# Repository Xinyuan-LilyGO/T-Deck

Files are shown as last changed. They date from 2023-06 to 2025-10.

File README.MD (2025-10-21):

<h1 align = "center">✨ LilyGO T-Deck  ✨</h1>

## **English | [中文](README_CN.MD)**

## News:

1. T-Deck-Plus has assigned the pins on the **Grove** interface to the GPS module, so the **Grove** interface of T-Deck-Plus cannot be used.
2. T-Deck updated [TFT_eSPI ST7789 initialization sequence](https://github.com/Xinyuan-LilyGO/T-Deck/commit/6adb8884c689f174c29a6d7172a0daa367a582eb) on 20240726. Currently, the changes have not been pushed to the TFT_eSPI upstream branch. If you find that the screen display is incorrect during use, please check whether this is consistent with the initialization sequence in the warehouse.

## 1️⃣ Examples preview

````
examples 
├─Keyboard_ESP32C3       # ESP32C3 keyboard I2C slave
├─Keyboard_T_Deck_Master # T-Deck read from keyboard
├─LoRaWAN_Starter        # LoRaWAN example
├─Microphone             # Noise detection  
├─Touchpad               # Read touch coordinates 
├─GPSShield              # GPS Shield example
├─lvgl_example           # lvgl example
└─UnitTest               # Factory hardware unit testing           

````

## 2️⃣ Quick Start

### PlatformIO

1. Install [VisualStudioCode](https://code.visualstudio.com/) and [Python](https://www.python.org/)
2. Search for the `PlatformIO` plugin in the `VisualStudioCode` extension and install it.
3. After the installation is complete, you need to restart `VisualStudioCode`
4. After restarting `VisualStudioCode`, select `File` in the upper left corner of `VisualStudioCode` -> `Open Folder` -> select the `T-Deck` directory
5. Click on the `platformio.ini` file, and in the `platformio` column, cancel the sample line that needs to be used, please make sure that only one line is valid
6. Click the (✔) symbol in the lower left corner to compile
7. Connect the board to the computer USB
8. Click (→) to upload firmware
9. Click (plug symbol) to monitor serial output

Optional:

You can upload the assets contents for the speaker demo, using the "Upload Filesystem Image" on PlatformIO menu.

### ArduinoIDE

1. Install [Arduino IDE](https://www.arduino.cc/en/software)
2. In Arduino Preferences, on the Settings tab, enter the `https://raw.githubusercontent.com/espressif/arduino-esp32/gh-pages/package_esp32_index.json` URL in the `Additional boards manager URLs` input box. **Please pay attention to the version. The test phase is using 2.0.14. It is not certain that versions above 2.0.14 can run. When the operation is abnormal, please downgrade to a version below 2.0.14.** , As of 2024/08/02, TFT_eSPI does not work on versions higher than 2.0.14, see [TFT_eSPI/issue3329](https://github.com/Bodmer/TFT_eSPI/issues/3329)
3. Copy all the folders in the `T-Deck/lib` directory to `<C:\Users\UserName\Documents\Arduino\libraries>`. If there is no `libraries` directory, please create a new one. Please note that you are not copying the `lib` directory, but copying the folders in the lib directory
4. Open ArduinoIDE  ,`Tools` , Look at the picture to choose
    | T-Deck(ESP32S3)      | T-Keyboard(ESP32C3)  |
    | -------------------- | -------------------- |
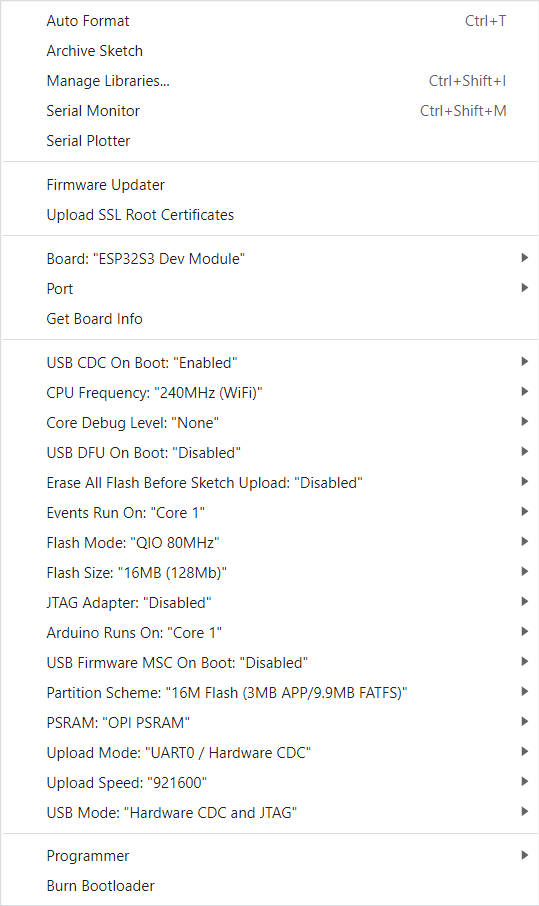
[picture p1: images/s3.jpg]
s3
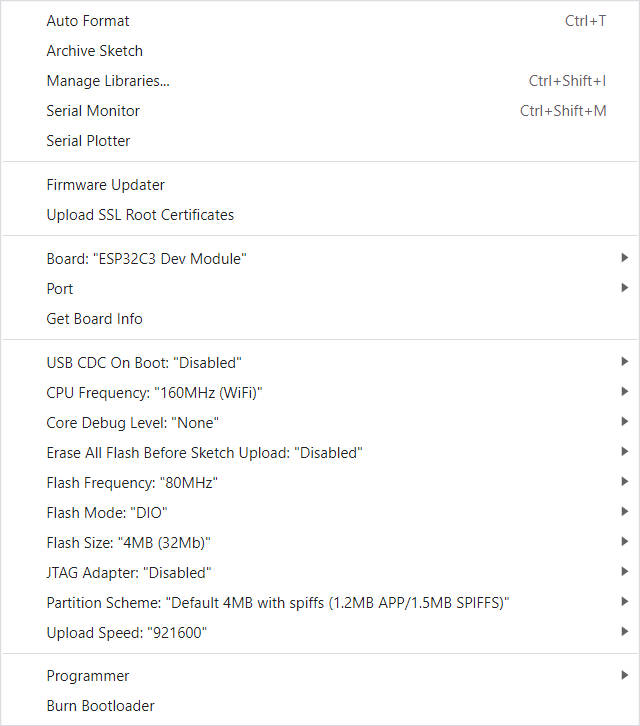
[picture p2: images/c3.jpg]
c3
    |  |  |
5. Insert USB into the PC and click Upload <If the upload fails, keep pressing the BOOT button, click RST, and then click Upload. When the upload is complete, click RST to exit the download mode>

## 3️⃣ Tips:

1. If a microphone is used, the GPIOO button cannot be used
2. If the sketch cannot be uploaded, then you need to press down the middle of the trackball, and then insert the USB, this means the chip is in the download mode, and then click to upload the sketch.
3. T-Keyboard the programming and burning interface of ESP32C3 is located at the 6Pin header on the side of the RST button, and the order starts from the top of the RST button, which are TX,RX,BOOT,RST,GND,VCC, You need to connect USB TO TTL externally to burn the keyboard firmware. For TTL without automatic download circuit, before powering on, short-circuit the BOOT Pin and GND, and then power on. At this time, T-Keyboard will enter the download mode. After the burning is completed, you need to disconnect GND and BOOT before running the program.

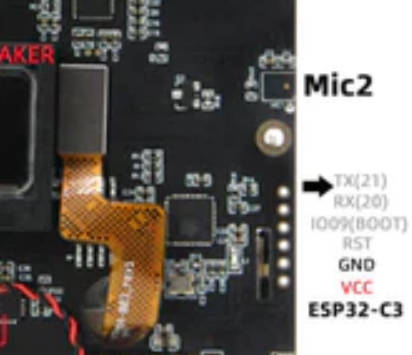
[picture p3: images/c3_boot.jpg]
c3_boot
   

4. T-Deck can't upload any sketch，Please enter the upload mode manually.
   1. Connect the USB-C cable
   2. Toggle the switch to ON
   3. Press and hold the center trackball
   4. Press the left reset button
   5. Upload sketch
   6. If you still cannot upload the sketch successfully according to the above method, please check whether the resistor in this [issue62](https://github.com/Xinyuan-LilyGO/T-Deck/issues/62) exists. Please remove it and test again.
   7. [How to enter download mode Youtube](https://youtu.be/29g97dYt9-g)

5. fatal error: esp_vad.h: No such file or directory
   1. See [issus](https://github.com/Xinyuan-LilyGO/T-Deck/issues/90#issuecomment-2980116659)

## 4️⃣ Where to buy:

1. [AliExpress](https://www.aliexpress.com/item/1005005692235592.html)
2. [LilyGo Store](https://www.lilygo.cc/products/t-deck)

## 5️⃣ Pins:

See [utilities.h](./examples//UnitTest//utilities.h)

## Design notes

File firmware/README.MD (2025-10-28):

# Write to new users

- This page provides a quick diagnosis of whether the hardware is normal. The firmware in the example table below provides quick testing of the hardware. Please follow the steps below to test
- [T-Deck Plus Touch Fix Record](https://youtu.be/CTdMXJvWZpA)
- [How to write firmware to T-Deck or T-Deck-Plus Record](https://www.youtube.com/watch?v=aSjUyzw_2F4)
- [Discussion about touch repair](https://www.reddit.com/r/meshtastic/comments/1jizmsb/tdeck_touchscreen_not_working_properly/)
- **Please note that if meshtastic is written, the port displayed after plugging in the computer USB is a virtual USB port, not a real port number. You must manually enter the download mode to perform the secondary flash. For how to enter the download mode, please see the FAQ below.**

# 1️⃣ Quickly diagnose hardware

| Firmware Name | description |
| --- | --- |
| [T-Keyboard_Keyboard_ESP32C3_250620.bin](./T-Keyboard_Keyboard_ESP32C3_250620.bin) | [T-Deck Keyboard C3 firmware][1] |
| [T-Deck_UnitTest_241220.bin](./T-Deck_UnitTest_241220.bin) | [T-Deck/T-Deck-Plus function test firmware][1] |
| [T-Deck-Plus-TouchFix_241025.bin](./T-Deck-Plus-TouchFix_241025.bin) | [T-Deck-Plus Touch Fix][2] |
| [T-Deck-Plus-TouchFix_241203.bin](./T-Deck-Plus-TouchFix_241203.bin) | [T-Deck-Plus Touch Fix][2] |
| [Meshtastic Online][https://flasher.meshtastic.org/] | [Meshtastic Online][https://flasher.meshtastic.org/] |

⚠⚠⚠

**T-Deck-Plus-TouchFix_241025.bin** Touch repair program, can only be flashed on rounded corner screens, please do not flash this on T-Deck rectangular screens, otherwise the screen touch will fail

**T-Deck-Plus-TouchFix_241025.bin** Touch repair program, can only be flashed on rounded corner screens, please do not flash this on T-Deck rectangular screens, otherwise the screen touch will fail

**T-Deck-Plus-TouchFix_241025.bin** Touch repair program, can only be flashed on rounded corner screens, please do not flash this on T-Deck rectangular screens, otherwise the screen touch will fail

[1]: https://www.lilygo.cc/products/t-deck
[2]: https://www.lilygo.cc/products/t-deck
[3]: https://www.lilygo.cc/products/t-deck

### Use ESP Download Tool

- Download [Flash_download_tool](https://www.espressif.com.cn/sites/default/files/tools/flash_download_tool_3.9.7_0.zip)

web_flasher

* Note that after writing is completed, you need to press RST to reset.
* When writing the keyboard firmware, you need to select ESP32-C3 in the chip type

### Use Web Flasher

- [ESP Web Flasher Online](https://espressif.github.io/esptool-js/)

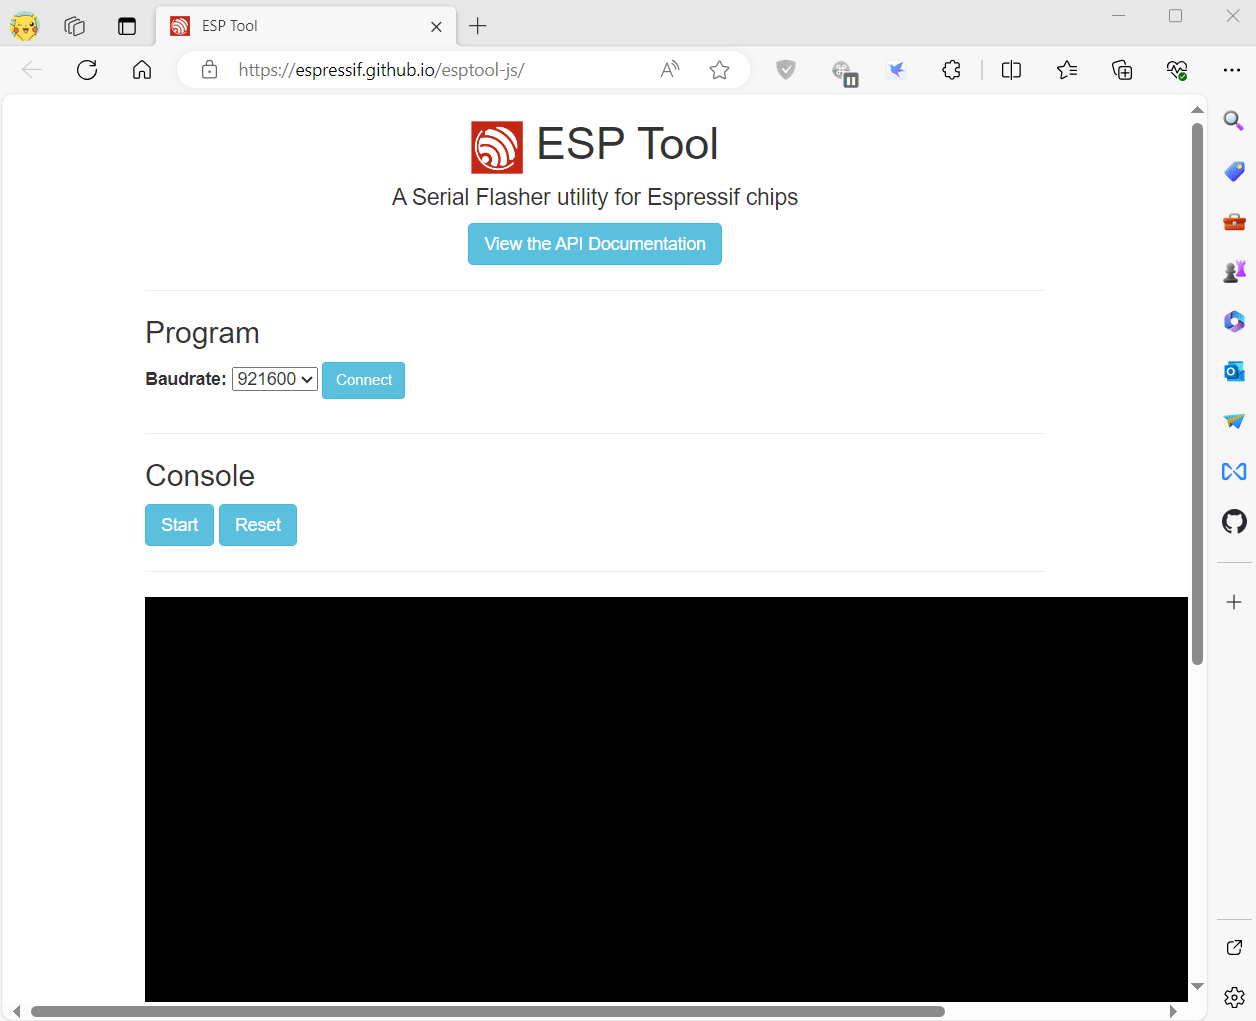
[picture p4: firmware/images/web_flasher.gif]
web_flasher


* Note that after writing is completed, you need to press RST to reset.

### Use command line

If system asks about install Developer Tools, do it.

```bash
python3 -m pip install --upgrade pip
python3 -m pip install esptool
```

In order to launch esptool.py, exec directly with this:

```bash
python3 -m esptool
```

For T-Deck/T-Deck-Plus use the following command to write

```bash
esptool --chip esp32s3  --baud 921600 --before default_reset --after hard_reset write_flash -z --flash_mode dio --flash_freq 80m 0x0 T-Deck_UnitTest_241004.bin

```

For ESP32-C3 Keyboard use the following command to write

```bash
esptool --chip esp32c3  --baud 921600 --before default_reset --after hard_reset write_flash -z --flash_mode dio --flash_freq 80m 0x0 firmware-c3-t-keyboard.bin

```

# 2️⃣FAQ

- Can't upload any sketch，Please enter the upload mode manually.
   1. Connect the board via the USB cable
   2. Press and hold the **BOOT** button , While still pressing the **BOOT** button (On the trackball above the keyboard, press down)
   3. Press **RST** button
   4. Release the **RST** button
   5. Release the **BOOT** button (If there is no **BOOT** button, disconnect IO0 from GND.)
   6. Upload sketch
   7. Press the **RST** button to exit download mode

- T-Keyboard the programming and burning interface of ESP32C3 is located at the 6Pin header on the side of the RST button, and the order starts from the top of the RST button, which are TX,RX,BOOT,RST,GND,VCC, You need to connect USB TO TTL externally to burn the keyboard firmware. For TTL without automatic download circuit, before powering on, short-circuit the BOOT Pin and GND, and then power on. At this time, T-Keyboard will enter the download mode. After the burning is completed, you need to disconnect GND and BOOT before running the program.

   c3_boot

## Touch Fix firmware

- Used to try to repair the touch when the touch does not work properly. If the hardware is not damaged, then open the serial after writing, you should be able to see the following log, slide your finger on the touch screen, and you can see the output sliding coordinates

   ```bash

   ESP-ROM:esp32s3-20210327
   Build:Mar 27 2021
   rst:0x15 (USB_UART_CHIP_RESET),boot:0x8 (SPI_FAST_FLASH_BOOT)
   Saved PC:0x420247ee
   SPIWP:0xee
   mode:DIO, clock div:1
   load:0x3fce3808,len:0x44c
   load:0x403c9700,len:0xbe4
   load:0x403cc700,len:0x2a38
   entry 0x403c98d4
   [    88][I][esp32-hal-psram.c:96] psramInit(): PSRAM enabled
   [    94][I][esp32-hal-i2c.c:75] i2cInit(): Initialising I2C Master: sda=18 scl=8 freq=100000
   [    94][I][SensorCommon.tpp:65] begin(): Using Arduino Wire interface.
   [    97][W][Wire.cpp:301] begin(): Bus already started in Master Mode.
   [   104][D][TouchDrvGT911.hpp:584] initImpl(): Probe address ....
   [   112][D][TouchDrvGT911.hpp:588] initImpl(): Probe address is : 0x5D
   [   138][I][TouchDrvGT911.hpp:644] initImpl(): Product id:911
   [   138][D][TouchDrvGT911.hpp:653] initImpl(): Current version char :41
   [   256][D][TouchDrvGT911.hpp:659] initImpl(): WriteConfig version char :0
   [   257][I][TouchDrvGT911.hpp:666] initImpl(): Firmware version: 0x1060
   [   260][I][TouchDrvGT911.hpp:668] initImpl(): Resolution : X = 240 Y = 320
   [   265][I][TouchDrvGT911.hpp:669] initImpl(): Vendor id:57
   [   270][I][TouchDrvGT911.hpp:670] initImpl(): Refresh Rate:10 ms
   [   276][I][TouchDrvGT911.hpp:671] initImpl(): MaxTouchPoint:5
   [   282][I][TouchDrvGT911.hpp:680] initImpl(): Interrupt Mode:  FALLING
   Init GT911 Sensor success!
   Pressed!
   2093ms X[0]:86  Y[0]:152 
   Pressed!
   2198ms X[0]:86  Y[0]:152 
   Pressed!

   ```

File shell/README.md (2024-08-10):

## DXF

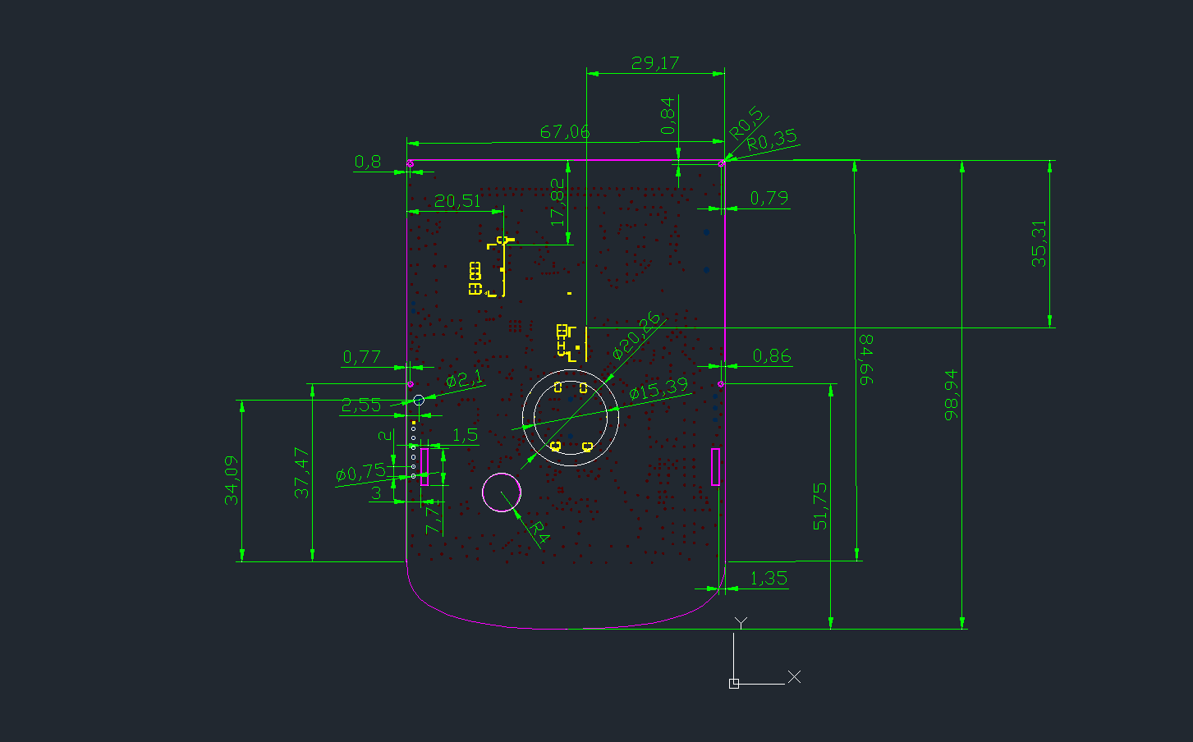
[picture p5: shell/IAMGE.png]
IAMGE


## PCB_3D

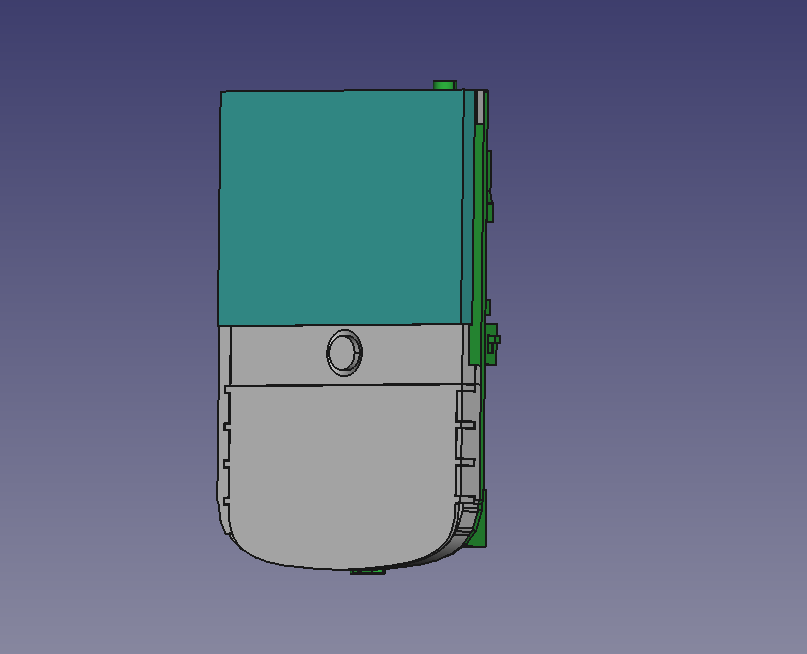
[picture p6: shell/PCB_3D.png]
PCB_3D


## SHELL_3D

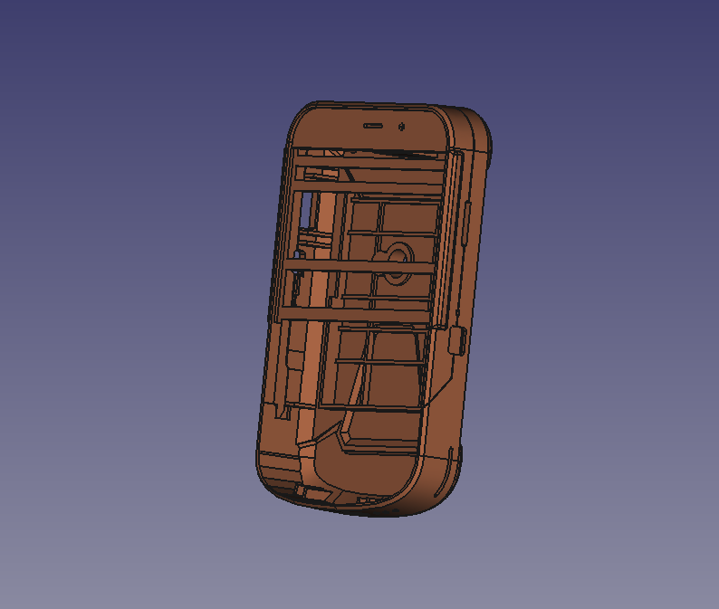
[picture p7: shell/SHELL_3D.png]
SHELL_3D


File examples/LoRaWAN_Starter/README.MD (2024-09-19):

## [LoRaWAN_Starter , Must read for new users](https://github.com/jgromes/RadioLib/blob/master/examples/LoRaWAN/LoRaWAN_Starter/notes.md)

## Operation screenshot

### [thethingsnetwork website](https://www.thethingsnetwork.org/)

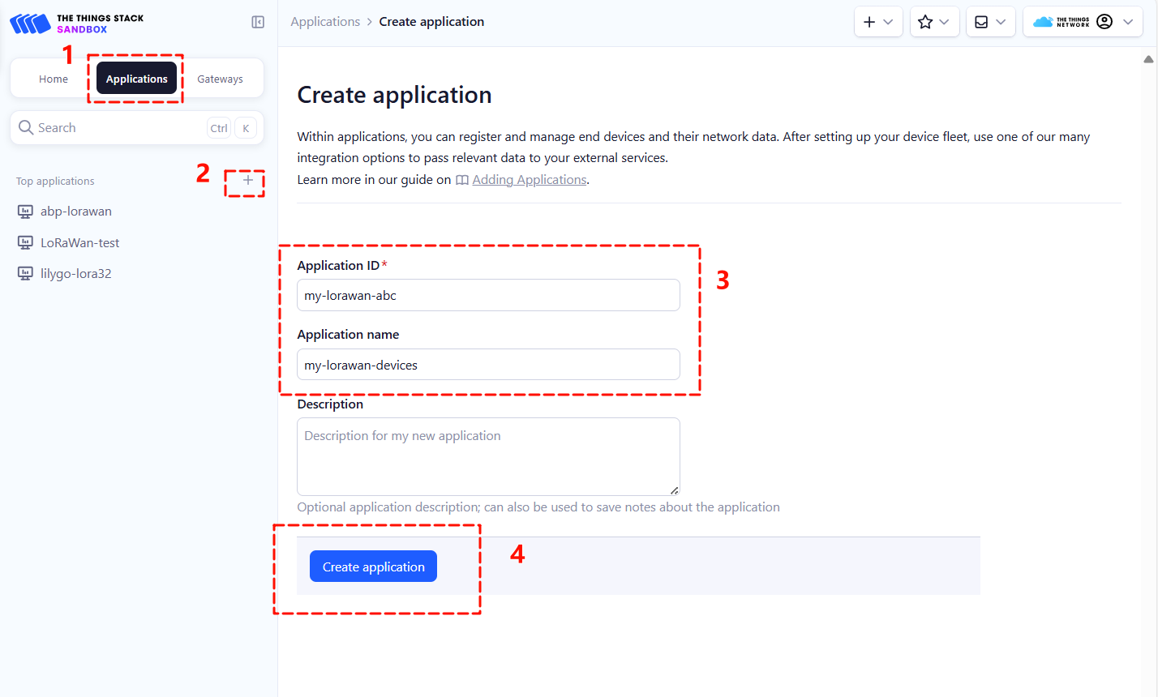
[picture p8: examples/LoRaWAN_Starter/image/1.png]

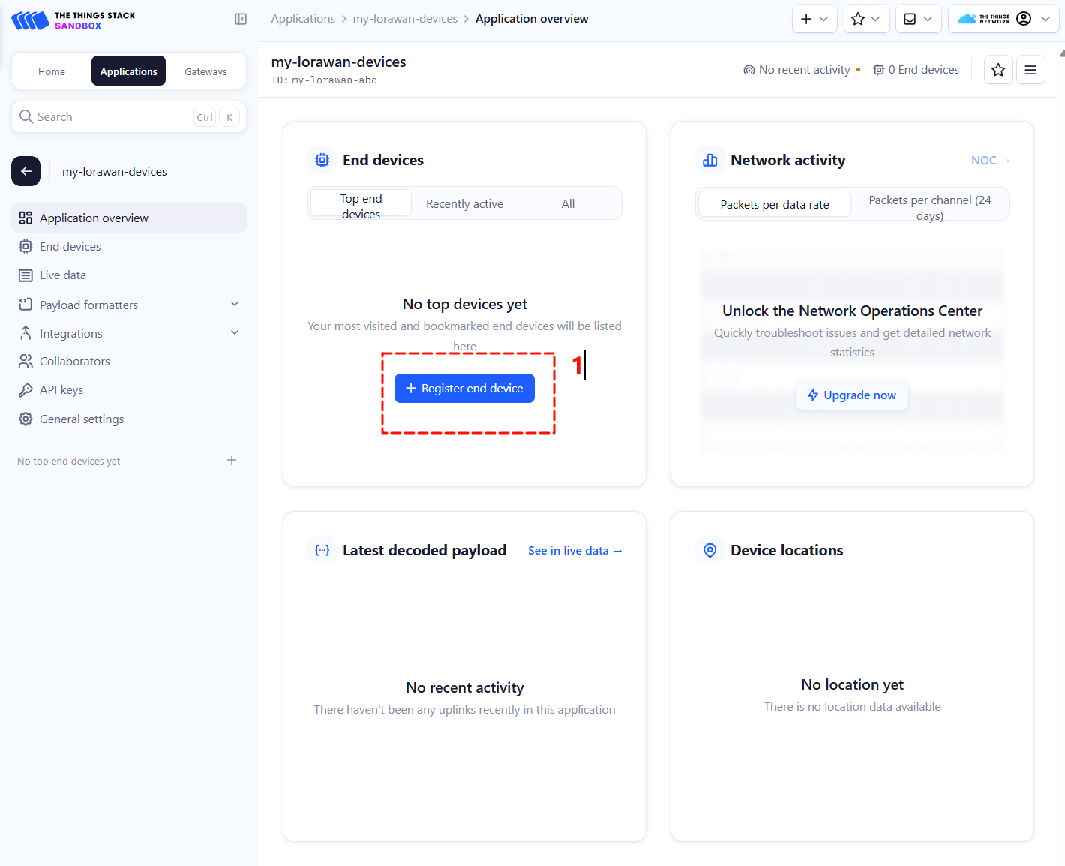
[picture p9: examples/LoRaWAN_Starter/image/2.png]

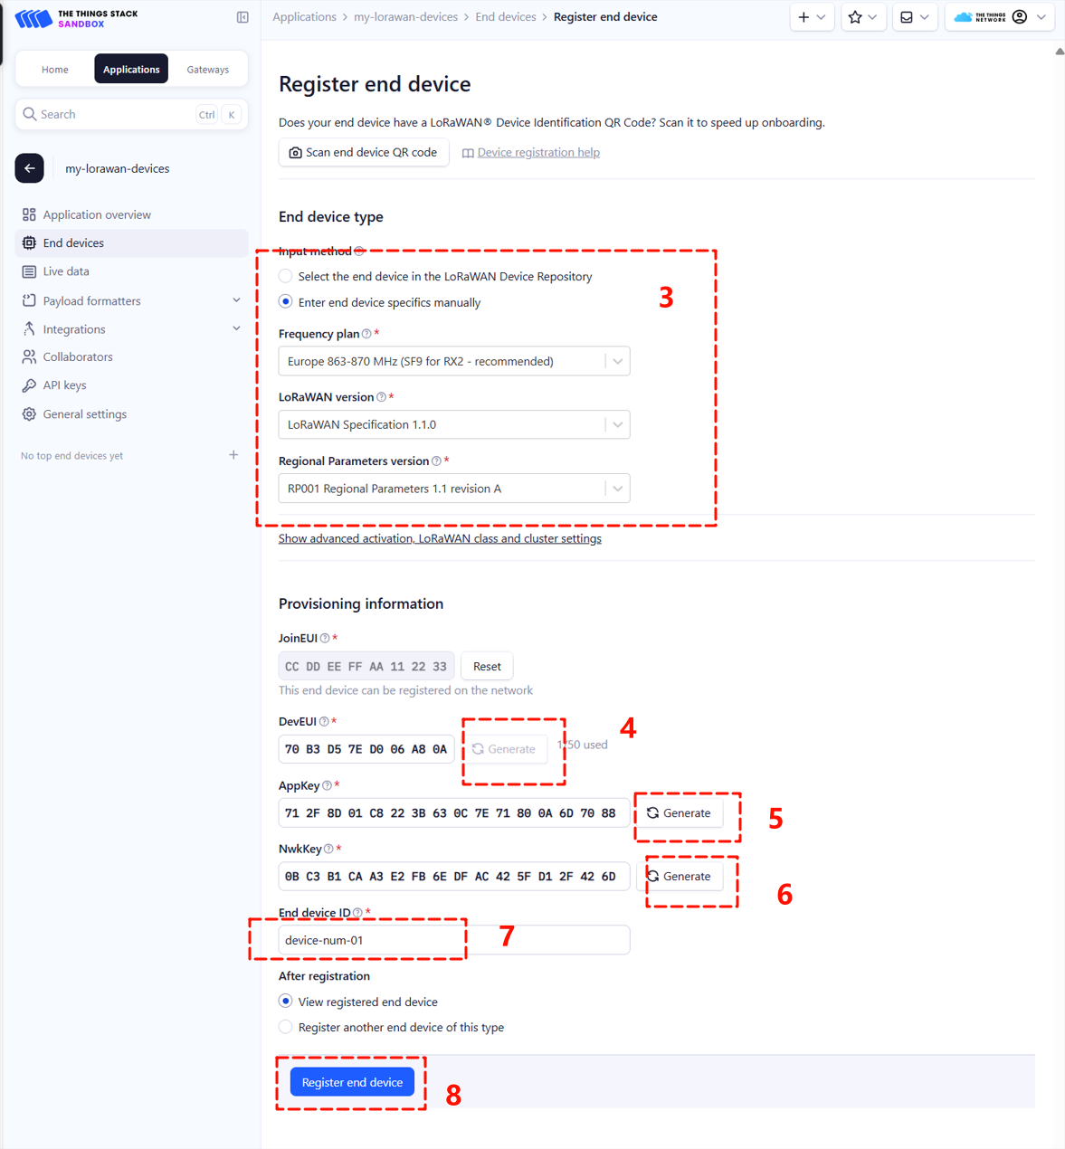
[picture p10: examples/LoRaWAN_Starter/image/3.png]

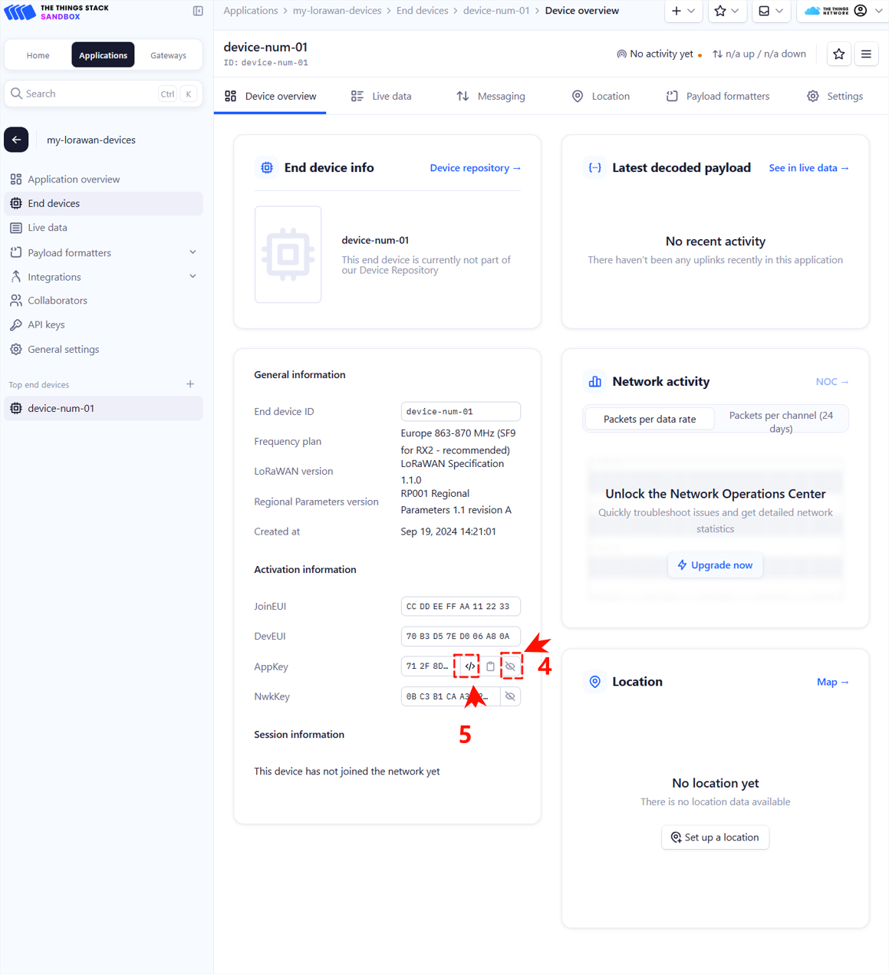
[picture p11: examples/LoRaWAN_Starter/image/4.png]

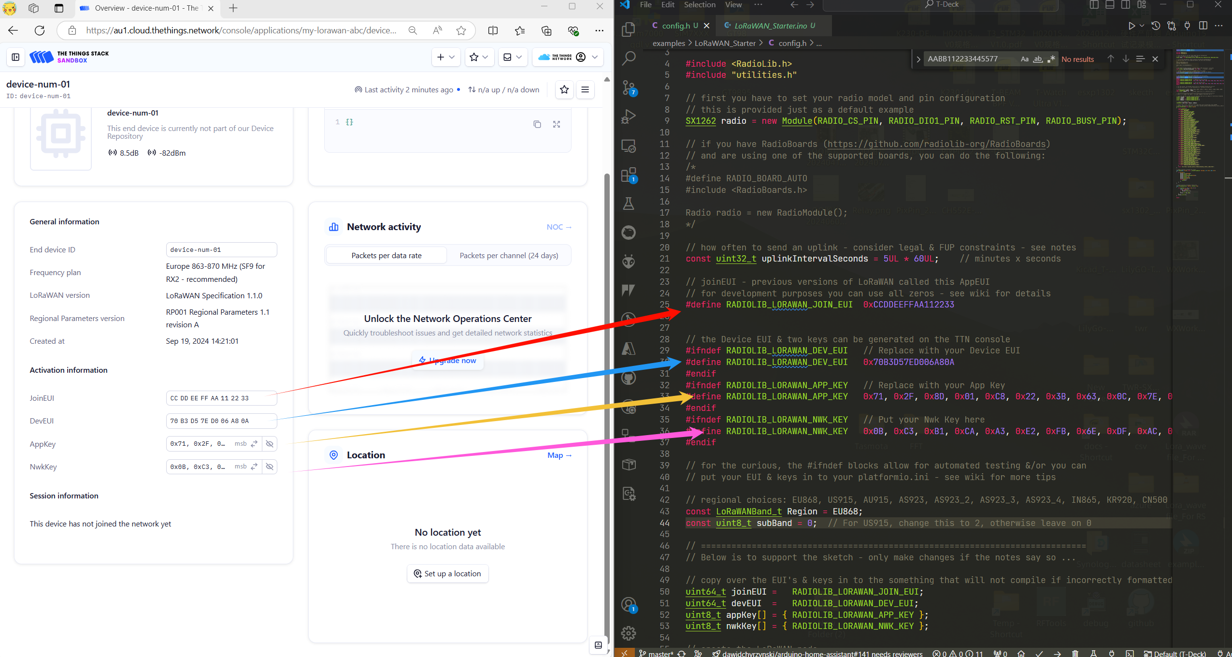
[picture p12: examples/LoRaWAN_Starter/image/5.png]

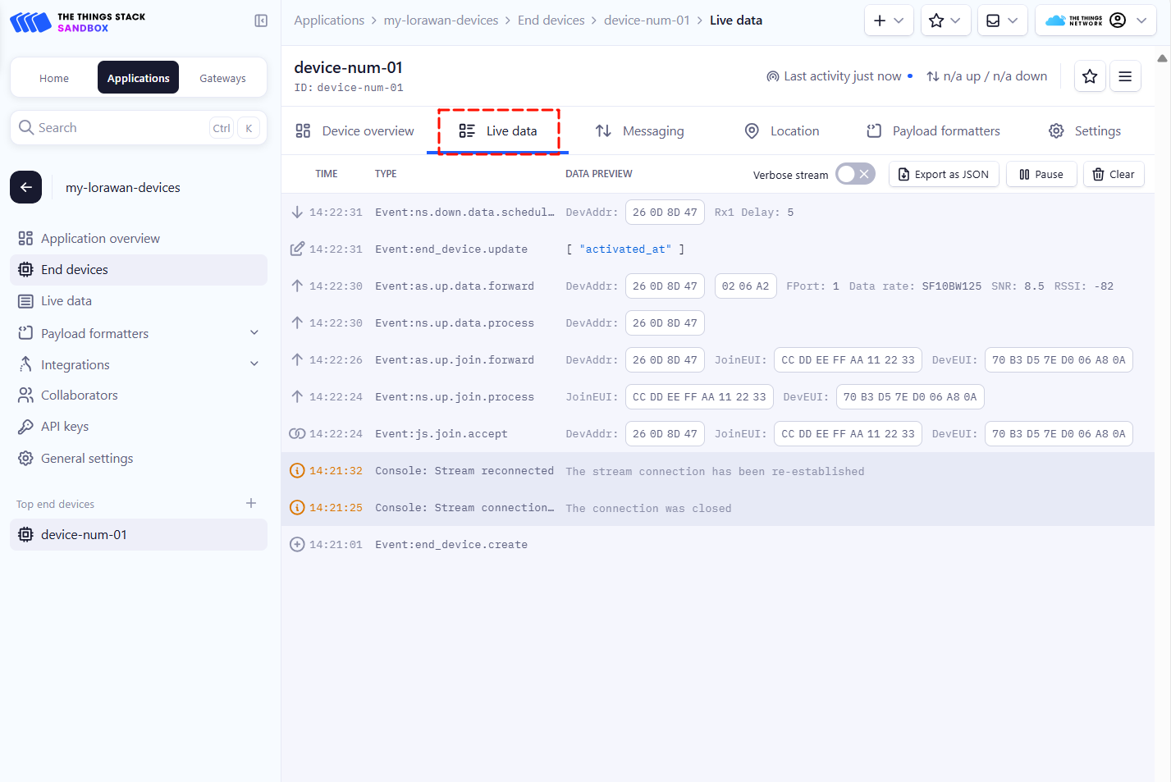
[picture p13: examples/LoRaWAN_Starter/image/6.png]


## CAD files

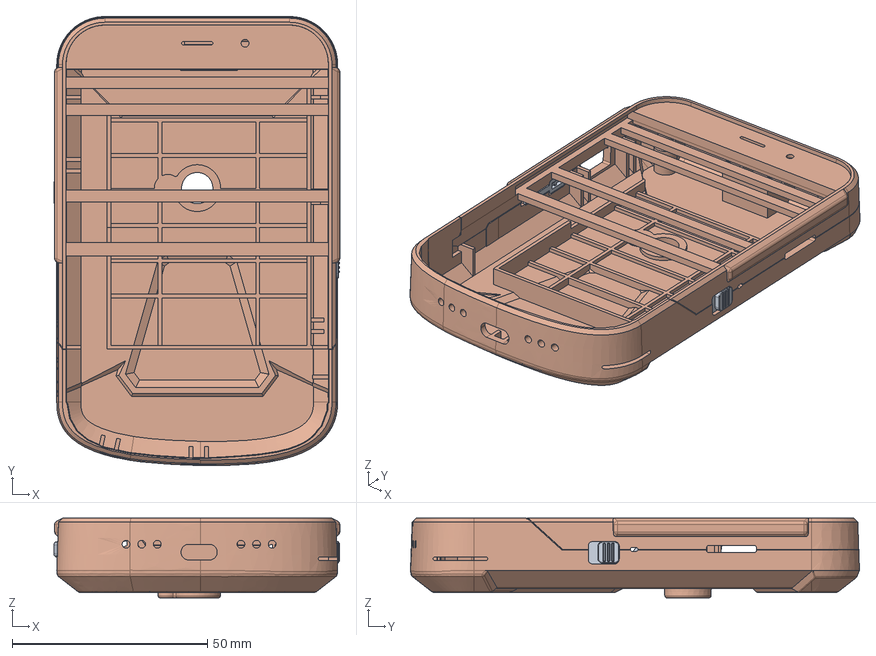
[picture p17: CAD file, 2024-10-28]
shell/T-Deck-Plus-Shell.stp
73.1 x 115.0 x 20.4 mm
0-KEY1_8
0-KEY2_8
ASM0001_ASM_215_ASM_3_ASM_2
0-00_6_ASM_1_ASM_2
D_36_4
PRT0003_182_46_32

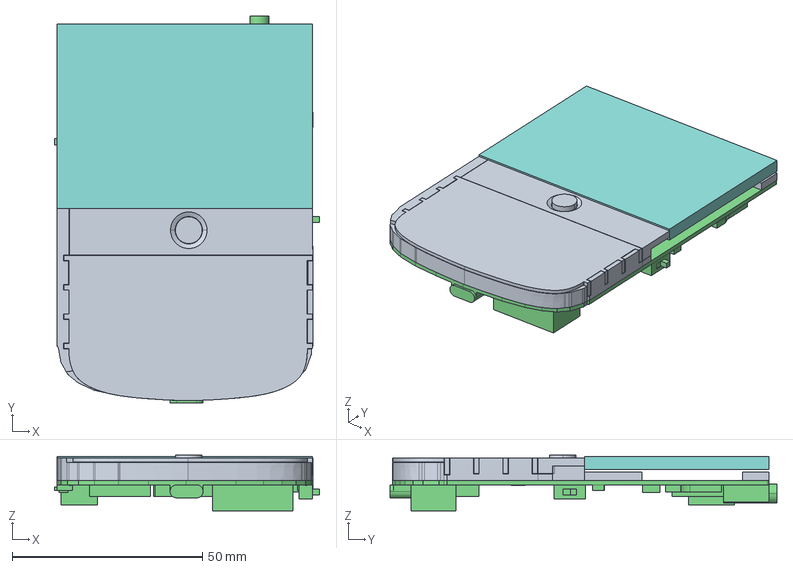
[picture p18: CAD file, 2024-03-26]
shell/T-Deck-PCB-3D.stp
69.6 x 101.5 x 14.6 mm
MANIFOLD_SOLID_BREP_216_1_1
0-PCB_16_13

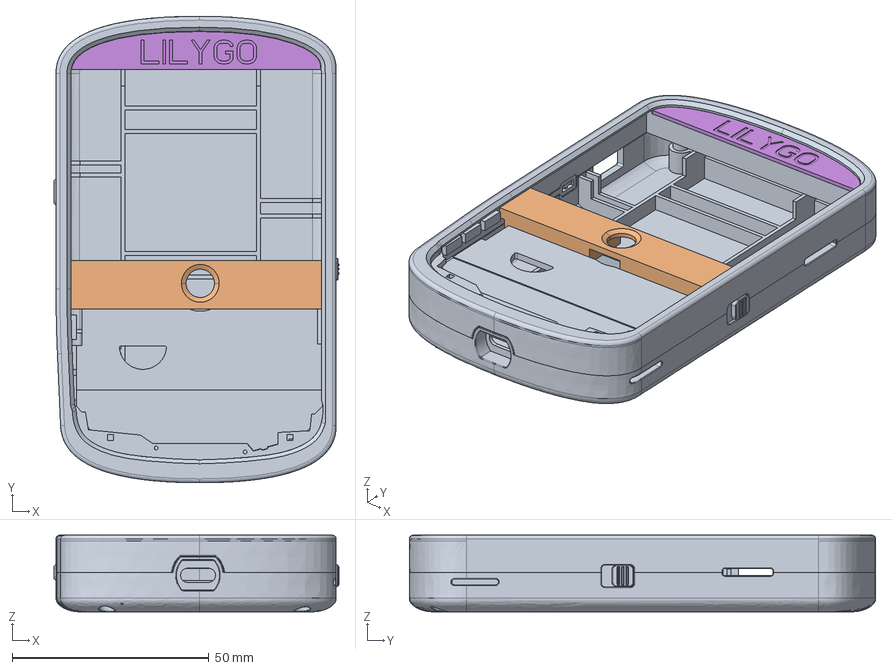
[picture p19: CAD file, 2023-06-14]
shell/T_Deck_2.stp
72.5 x 118.6 x 19.5 mm
0-PMMA_57
0-KEY1
0-KEY2
PRT0001

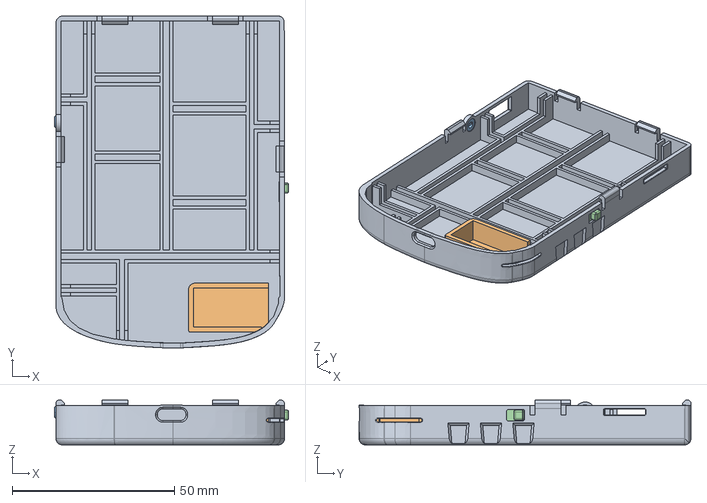
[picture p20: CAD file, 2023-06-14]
shell/T_Deck_1.stp
72.1 x 102.2 x 13.8 mm

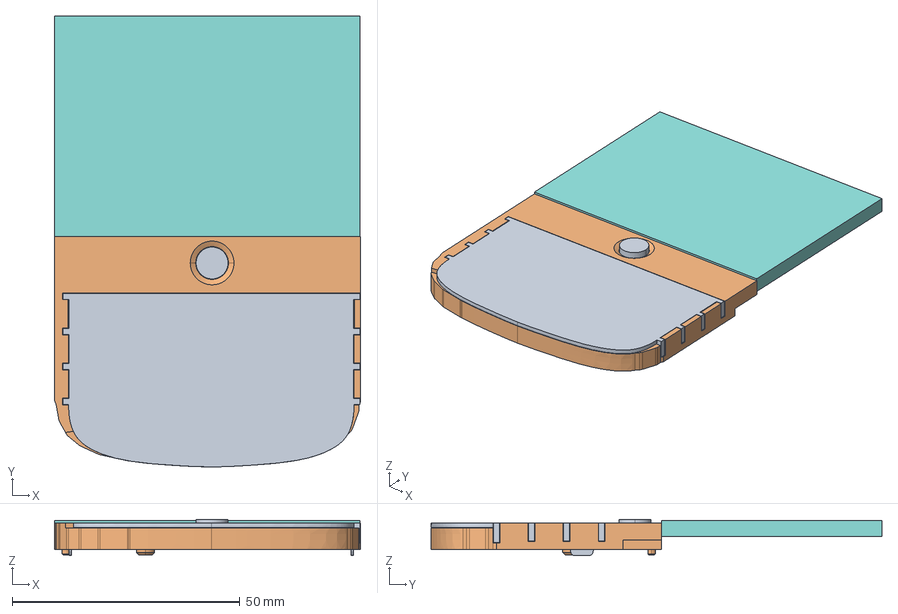
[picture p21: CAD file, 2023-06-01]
shell/T-Deck.stp
67.2 x 99.0 x 8.00 mm
0-PMMA
MANIFOLD_SOLID_BREP_216_1_1

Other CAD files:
shell/T-Deck-Shell.stp
shell/T-Deck.dxf

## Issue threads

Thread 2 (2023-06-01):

UnitTest Example not Compiling

tomvdb, 2023-06-01:
Hi There,

All examples seems to compiling and working fine, except for the UnitTest example. It seems to be looking for lv_conf.h

All libraries are correctly installed. Maybe a file is missing ?

`In file included from c:\users\admin\documents\arduino\libraries\lvgl\src/misc/lv_log.h:16,
                 from c:\users\admin\documents\arduino\libraries\lvgl\lvgl.h:25,
                 from C:\Users\admin\Documents\Arduino\libraries\lvgl\src/lvgl.h:17,
                 from C:\temp\T-Deck-master\examples\UnitTest\UnitTest.ino:13:
c:\users\admin\documents\arduino\libraries\lvgl\src\lv_conf_internal.h:41:18: fatal error: ../../lv_conf.h: No such file or directory
         #include "../../lv_conf.h"                /*Else assume lv_conf.h is next to the lvgl folder*/
                  ^~~~~~~~~~~~~~~~~
compilation terminated.
exit status 1
Error compiling for board ESP32S3 Dev Module.
`

lewisxhe, 2023-06-07:
Move ` lvgl/lv_conf.h` into the `libraries` directory.
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

tomvdb, 2023-06-08:
Thank you :)

Closed 2023-06-07.

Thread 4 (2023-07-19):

ESP32C3 Programming

hypercreeper, 2023-07-19:
Im having issues with the Keyboard_ESP32C3 Example, when i try to upload the example to the esp32c3, it will bootloop with this message:
```Build:Feb  7 2021
rst:0x3 (RTC_SW_SYS_RST),boot:0xd (SPI_FAST_FLASH_BOOT)
Saved PC:0x403cf80c
SPIWP:0xee
mode:DIO, clock div:1
load:0x3fcd5810,len:0x438
load:0x403cc710,len:0x918
load:0x403ce710,len:0x24e4
entry 0x403cc710
ESP-ROM:esp32c3-api1-20210207
Build:Feb  7 2021
rst:0x3 (RTC_SW_SYS_RST),boot:0xd (SPI_FAST_FLASH_BOOT)
Saved PC:0x403cf80c
SPIWP:0xee
mode:DIO, clock div:1
load:0x3fcd5810,len:0x438
load:0x403cc710,len:0x918
load:0x403ce710,len:0x24e4
entry 0x403cc710
ESP-ROM:esp32c3-api1-20210207
Build:Feb  7 2021
rst:0x3 (RTC_SW_SYS_RST),boot:0xd (SPI_FAST_FLASH_BOOT)
Saved PC:0x403cf80c
SPIWP:0xee
mode:DIO, clock div:1
load:0x3fcd5810,len:0x438
load:0x403cc710,len:0x918
load:0x403ce710,len:0x24e4
entry 0x403cc710
```
But when i upload the firmware from the firmware folder it works, but the example doesnt work and keeps bootlooping

hypercreeper, 2023-07-19:
Solved by adding `board_build.flash_mode = dio` to the `[env:T-Keyboard]` in the `platformio.ini` file

hypercreeper, 2023-07-19:
> Solved by adding `board_build.flash_mode = dio` to the `[env:T-Keyboard]` in the `platformio.ini` file

This solution breaks i2c with this error:
```
E (2341) i2c: i2c_set_pin(870): sda gpio number error
[  1950][E][esp32-hal-i2c.c:88] i2cInit(): i2c_param_config failed
```
ESP32C3 cannot communicate with ESP32S3

lewisxhe, 2023-07-24:
First you have to set the default env to T-Keybord Did you do that? As shown below :

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

I have tested everything is normal, because board = ttgo-t-oi-plus the default flash mode is dio

mischief, 2023-08-28:
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

see #10 - there is a weird bug with function overloading in the Wire class that causes the sketch in the repo to try to setup as a master, not slave.

hypercreeper, 2023-08-28:
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

Thank you so much, I've been using the default bin file for the time being but I will try this fix and see if it works.

Closed 2023-08-28.

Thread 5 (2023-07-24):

Problem with boot mode on T-Deck

bryanlyon, 2023-07-24:
I have 3 t-decks.  Unfortunately one of them corrupted during a download, since then I have been unable to get it to take an new firmware.

I can (sometimes) get it to boot into the rom bootloader mode by holding down the trackball while resetting, however, once I try to use the esptool it finds the com port, but times out in writing.

```
esptool.py v4.5.1
Serial port /dev/ttyACM0
Connecting....

A serial exception error occurred: Write timeout
```
I have tried this also on other computers with identical results.  I've also tried putting my working T-decks into bootloader mode and while I can get them to bootloader mode the results are identical to my failed T-Deck.

The good ones will still take updated firmware while running normally, but the failed T-Deck will not, as it continually resets the USB connection.

With trace enabled in esptool I get the following:
```
esptool.py v4.6.2
Serial port /dev/ttyACM0
Connecting...TRACE +0.000 command op=0x08 data len=36 wait_response=1 timeout=0.100 data=
    0707122055555555 5555555555555555 | ... UUUUUUUUUUUU
    5555555555555555 5555555555555555 | UUUUUUUUUUUUUUUU
    55555555                          | UUUU
TRACE +0.000 Write 46 bytes:
    c000082400000000 0007071220555555 | ...$........ UUU
    5555555555555555 5555555555555555 | UUUUUUUUUUUUUUUU
    5555555555555555 5555555555c0     | UUUUUUUUUUUUU.

A serial exception error occurred: Write timeout
```

I've tried forcing the chip with --chip esp32s3 (and esp32) as well as various baud rates.  Everything I try fails with the write timeout.

Connection is successful and I get data from the chip when I do:

```
[Fri Jul 21 10:05:03 2023] usb 1-2.4: new full-speed USB device number 95 using xhci_hcd
[Fri Jul 21 10:05:03 2023] usb 1-2.4: New USB device found, idVendor=303a, idProduct=1001, bcdDevice= 1.01
[Fri Jul 21 10:05:03 2023] usb 1-2.4: New USB device strings: Mfr=1, Product=2, SerialNumber=3
[Fri Jul 21 10:05:03 2023] usb 1-2.4: Product: USB JTAG/serial debug unit
[Fri Jul 21 10:05:03 2023] usb 1-2.4: Manufacturer: Espressif
[Fri Jul 21 10:05:03 2023] usb 1-2.4: SerialNumber: 34:85:18:A6:34:44
[Fri Jul 21 10:05:03 2023] cdc_acm 1-2.4:1.0: ttyACM0: USB ACM device
```

But any attempt to write or to erase the flash fails with a write timeout.

This is reproducable on all 3 of my T-Decks when in bootloader mode (and on multiple computers), but like I said, 2 of them can get flashed normally in the non-bootloader mode.

bkircher67, 2023-07-26:
I have the same issues. erase_flash works fine on T-HMI and on T-Display-S3 but the T-Desk either times out (non bootloader mode) or stalls (bootloader mode by pressing the trackball-button). I also tried it under Windows 11 and on MacOS.
I only once was able to install Micropython .. probably this bricked my T-Desk.

lewisxhe, 2023-07-28:
Try this method!

https://github.com/Xinyuan-LilyGO/T-Deck/tree/master/firmware

bryanlyon, 2023-08-01:
Unfortunately the linked instructions are the ones I've already followed and does not make bootloader mode work on the T-deck.  I am still unable to flash when the T-Deck is in bootloader mode on any of my devices.

lewisxhe, 2023-08-02:
Please take a photo of the PCB on ESP32S3 and show it to me.

bkircher67, 2023-08-03:
Hello, I tried all kinds of setting on the Windows Flasher, but I always see the same behaviour:
If not in bootloader-mode (on COM5): it just runs forever

```
test offset :  0 0x0
case ok
.................................................................................................................................................................................
```

if in bootload-mode (COM4 or COM7): it waits some seconds and returns with a message box saying:
```
2-sync fail:
Tips: Please refer to the chip dataset and confirm that strapping pin's status is correct.
```
KInd regards
Bernd

bkircher67, 2023-08-03:
Here's my PCB:
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

bryanlyon, 2023-08-03:
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
Here is mine.

bkircher67, 2023-08-04:
Thanks!

Removing D2 worked perfectly fine for me! Uploading new firmware is no longer a problem.

Kind regards

Bernd

MrSniffer, 2023-08-05:
I just received two T-Decks with the D2 jumper. Should they be removed in all cases? Kindly explain before I have the same problem.

RevClamJuice, 2023-08-05:
Can confirm. i was having the same problem and removing D2 fixed it.

karfas, 2023-08-13:
Had the very same problem.
Removing D2 works to use simple commands like chip_id.
However, I had to upgrade to esptool.py v4.7-dev (direct from the github repo) to get erase_flash etc. working.

YAMLcase, 2023-09-01:
Wow, talk about fast fix to the production line: I just received two T-Decks ordered 2 weeks ago and notice D2 is not installed on either.  I don't see any version info on the PCB though, is there any way to tell the difference?

danjperron, 2023-10-31:
Ok So I got a boot load problem and I did figure it out.  The ESP32-S3 need to have GPIO0 and GPIO46 to 0 to go into the boot load mode but the ESP32-C3 int is connected to the GPIO46 and disturb the very high resistor pull down value.

So shorting the GPIO46 and the same time that I press the GPIO0 button , then press the reset and release both GPIO0 and GPIO46 does the trick.    This tooks me 2 evenings to figure out why the T DecK didn`t want to go to boot load. I`m sure I`m not the only one with this problem.

sonic2wb, 2024-02-15:
THANK YOU THANK YOU,  fixed my issue uploading code. removing D2.

Closed 2024-10-03.

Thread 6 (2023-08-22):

T-Deck case/shell design files

mischief, 2023-08-22:
hi,

i received T-Deck recently in the mail and wanted a case.

there are design files in this git repo but i didn't have success using them. can you provide any instructions, or photos on their usage?

- T_Deck_1.stp: appears to be bottom case only, no front cover. is that expected?
- T_Deck_2.stp: i printed this, but the top cover doesn't seem to fit. there is parts of the model in the way where the keyboard/trackball is supposed to go and i didn't want to disassemble my t-deck keyboard for fear of breaking it.
- T-Deck.dxf: i can't use this file, does not work in freecad, free 3d editor for linux
- T-Deck.stp: doesn't look like a case.

i'm using freecad on gentoo linux to view the design files. it would be great if there was better support for making cases here. :smile:

ppetermann, 2023-09-19:
yeh, mine didn't fit into `T_Deck_2.stp` either - although what for me is in the way is the bottom of the keyboard not going into the top shell all the way.

derekmulcahy, 2023-10-13:
The t-deck must be partially disassembled then reassembled to make it fit in the case. The keyboard is held down by double sided tape. The case works quite well. There is a YouTube video of the process. I can find it if you can't. Good luck! The Meshtastic discord group has an #enclosures chat where various cases are being discussed.

makerdiaryid, 2023-10-29:
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

you can check my case for T-DECK
it have option to add RFID PN532

[T-DECK CASE](https://www.thingiverse.com/thing:6287501)

jharvey, 2023-12-11:
I've created a case in onshape. The source files can be found at the link below.
https://cad.onshape.com/documents/b289702058d3b69984c9ded4/w/4e1c5bb6efe28ab1e1699733/e/336c687f36e879030984626b

Some key notes about this layout.
- Flat sides are intentional so it can sit on a shelf or similar surface.
- It's a bit thicker to make it more robust. Feel free to make copies and modify it. It's still reasonably small, so I'm OK with the slightly thicker nature of this case layout.
- The front panel allows for different back panels to be installed, This back panel contains 18650 batteries. I plan to include circuits for short circuit, under voltage and a dedicated LION charger per cell. As of the time of writing this, the back panel is still a work in progress.
- Once GPS module arrives I plan to incorporate it into this back panel. I need it before I can measure and model it.
- I created a 3D PCB model using the Lilygo DXF and KiCAD. The components like USB jack etc. are probably not perfectly aligned. I suggest the PCB model be considered more of a rough estimate.
- Feel free to comment to me about this case layout. I'm open to suggestions and collaboration.

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

mischief, 2023-12-11:
@jharvey thanks. is there a way to edit and print this from Linux?

jharvey, 2023-12-11:
@mischief please open link and learn onshape. Onshape is in a browser and is independent of the operating system. It's kind of dependent on the browser. You should be able to make your own copy and modify that copy.

mischief, 2023-12-12:
unfortunately I do not have any interest in using a web based product like onshape for work or in using non free software that can't run on linux.

it would be great if we can share this in a public git repo in a 3d model format that can be edited and sliced for printing using free software.

zzbeakerzz, 2023-12-21:
Hey @jharvey, this is super neat! Have you had any time to continue messing with this? I actually really like the way you put all of this together. What are your thoughts of having some of this machined out of aluminum?

jharvey, 2023-12-22:
I recently got some charging boards. I'll 3D model them and incorporate them soon-ish during Christmas break. I've got overload/understand voltage protection boards coming. Those will be incorporated when I get them.

I kind of like the idea of metal, but that will likely de-tune the esp32 antenna. The Lora antenna would still be ok. But the other antenna which I don't plan to use would likely not work.

zzbeakerzz, 2023-12-24:
@jharvey well keep up the good work and consider me a subscriber! I think you have the most legit design out of the handful that are out there!

zzbeakerzz, 2024-01-08:
@jharvey I ended up having your model printed and it just arrived on Saturday. I am still waiting for the battery contactors to come in and I will get those installed and soldered together. Overall the case fits pretty nice! I had it printed in some heavy duty material so that I could modify it as needed. I ended up opening up the antenna hole to 1/4" to allow the connector to fit through (I can send you pictures if needed). I also opened up the screw head holes to 3/16" (this could have just been needed due to printing tolerances). With the material that I used for the print, I believe that the wall thickness could be reduced (40-50%?). I am also curious if a more cell phone battery shaped battery could be found (maybe 5,000 mAh? I have a few 3,000 mAh, but I like how big you went with the 3x 18650s). I only say that maybe a square LiPo could be used so that you could shrink the overall package. Overall, great job and I think that your model is my favorite to date!

jharvey, 2024-01-08:
@zzbeakerzz when did you send for print? I made some changes around Jan 1st 2024. Did those get printed? Pictures would be great. Knowing you printed makes me want to set a version in onshape so we have a record of it's status when it was printed.

Thanks for the feedback. I'll change the sma for sure. I need to better understand the 3/16 and 50% before I make those changes. Did you get the McMaster hardware from the onshape model? Perhaps hardware is different and perhaps I should allow clearance to accommodate for a wider range of hardware.

I've been fighting with my printer. It went so well that I've got a new printer showing up perhaps in 2 more days. This weekend end, I might have printing abilities again.

I'm picturing this will typically sit on a window sill with sunlight on the solar panel. Over time it should change the 18650's. I plan that it could also be a solar battery charger. I want to add a push button battery charger indicator, and easily removable batteries so I can hot swap and scoff off with the full batteries.

I plan for it to run with 0 to 3 batteries. If 0 battery then direct solar or plugged into wall is required. Currently it's got three purchased PCBs smashed in it. Once I know the circuit works, I plan to spin a PCB. It will look much better once I spin that PCB. For now I'd suggest only use 1 battery. If you put in a dead battery and a fully charged battery it would likely do bad things as the pack balanced out.

zzbeakerzz, 2024-01-13:
@jharvey, I shot you an email earlier this week. I am not sure if you had received it. But I did put a few photos in there. Let me know if you need any of the part numbers that I used.

jharvey, 2024-01-13:
@zzbeakerzz Yes I got the email. Sorry for not replying. Thanks for the pictures.

I've got the SV04 printing t-beam enclosures. I'm hoping to make good progress on this this weekend. Once I get the simpler t-beam to were I'm happy with it I'll print one of these and start picking away at this design. This one will take a lot longer to print.

zzbeakerzz, 2024-01-13:
Hey!
I figured this might be easier to talk and I was not sure if this was a
valid email! I did not mean to rush a response. I honestly just wanted to
make sure that you got my message and didn't think I was ignoring you.

-Nathan

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

jdcrunchman, 2024-03-04:
Why doesn't this have an SNA connector for connecting to my external antenna.   I looked at the site and the photos,  but I cannot see the antenna connection.    Can you please explain why?

fonix232, 2024-04-17:
@jdcrunchman SMA connectors are large and bulky for small integrated devices. The LoRa radio uses a u.FL/IPEX MHF1 connector, as do most other ESP based boards. The MCU itself uses an integrated antenna without the option for external connectivity so you'd need to replace the ESP32-S3 with a module that has a u.FL connector.

Nonetheless, u.FL can be adapted to SMA. However it's a bit rude to litter other issues with your unrelated problem :)

skippy814, 2024-05-05:
I have been greatly enjoying your case, it's the most robust and well planned out case I have ever seen. I did notice an issue with it, however. The ON and OFF labels are in the wrong place, but I am not sure if that's due to the board region or maybe a change LilyGo may have made to the boards at one time or what.

Great fit and finish for everything though. Best I have seen!

mischief, 2024-09-18:
considering the T-Deck Plus was recently released with it's own case design that is included, i will close this. thanks for everyone's responses. unfortunately, i did not find anything satisfactory for my own use case, and it would be great for the T-Deck Plus design files to be freely available in a format that is usable in free and open source 3d modelers, but that can be a separate issue.

Closed 2024-09-18.

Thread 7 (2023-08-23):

Missing file?

BugsTw, 2023-08-23:
“esp_vad.h: no such file or directory ”
Can’t seem to locate said missing file
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

Jokymon, 2023-08-28:
This file is part of the Espressif Speech Recognition SDK (https://github.com/espressif/esp-sr/tree/master/include/esp32s3) I would expect it to exist, when you correctly installed your PlatformIO setup before building.

jcampbellco, 2023-09-06:
Hi @Jokymon, hoping to get some guidance, I'm experiencing the same issue @BugsTw is, getting an `esp_vad.h: No such file or directory` error. In my case, it's with a fresh PlatformIO install and an unmodified clone of `master`, but I receive the same error:

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

Based on your comment that it should be pulled in via the Speech Recognition SDK, I added a line to platformio.ini, under the `[env:T-Deck]` section `lib_deps = https://github.com/espressif/esp-sr.git`, resulting in line 39 being added:

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

This pulled the `esp-sr` lib in, but `UnitTest.ino` was still reporting a file not found, poking around a bit I changed the `#include` line to `#include <esp32s3/esp_vad.h>`:

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

This does resolve the issue of `esp_vad.h` not being found, but in turn creates 3 new errors from `esp-sr` itself:

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

At this point I'm a little out of my depth with the dependency resolution happening here. Is this an issue that I'm on a Windows system? I will try and replicate later from my Linux machine.

If you have any suggestions on what this might point to, especially if it's something about my configuration of PlatformIO or anything of that sort, I really appreciate it! If there's any other info I can provide or steps I should take, happy to try and report back with results. Thank you again!

jcampbellco, 2023-09-07:
@BugsTw (and anyone else who finds this issue applies to them) I was able to modify `UnitTest.ino` to remove the `esp_vad.h` dependency pretty easily, here's a diff for it (also attached as `UnitTest.patch` for convenience).

If possible any help figuring out what I've configured incorrectly on PlatformIO or any suggestions there are very much appreciated still!

```
diff --git a/examples/UnitTest/UnitTest.ino b/examples/UnitTest/UnitTest.ino
index b21cdd8..03d4034 100644
--- a/examples/UnitTest/UnitTest.ino
+++ b/examples/UnitTest/UnitTest.ino
@@ -25,7 +25,6 @@
 #include "es7210.h"
 #include <Audio.h>
 #include <driver/i2s.h>
-#include <esp_vad.h>

 #define TOUCH_MODULES_GT911
 #include "TouchLib.h"
@@ -71,8 +70,6 @@ TFT_eSPI        tft;
 Audio           audio;
 size_t          bytes_read;
 uint8_t         status;
-int16_t         *vad_buff;
-vad_handle_t    vad_inst;
 TaskHandle_t    playHandle = NULL;
 TaskHandle_t    radioHandle = NULL;

@@ -803,34 +800,6 @@ void initBoard()
     i2s_set_pin(I2S_CH, &pin_config);
     i2s_zero_dma_buffer(I2S_CH);

-
-    vad_inst = vad_create(VAD_MODE_0);
-    vad_buff = (int16_t *)malloc(VAD_BUFFER_LENGTH * sizeof(short));
-    if (vad_buff == NULL) {
-        while (1) {
-            Serial.println("Memory allocation failed!");
-            delay(1000);
-        }
-    }
-
-    // Wait until sound is detected before continuing
-    uint32_t c = 0;
-    while (1) {
-        i2s_read(I2S_CH, (char *)vad_buff, VAD_BUFFER_LENGTH * sizeof(short), &bytes_read, portMAX_DELAY);
-        // Feed samples to the VAD process and get the result
-        vad_state_t vad_state = vad_process(vad_inst, vad_buff, VAD_SAMPLE_RATE_HZ, VAD_FRAME_LENGTH_MS);
-        if (vad_state == VAD_SPEECH) {
-            Serial.print(millis());
-            Serial.println("Speech detected");
-            c++;
-            snprintf(buf, 256, "%s:%d\n", "Speech detected", c);
-            addMessage(buf);
-        }
-        if (c >= 5)break;
-        lv_task_handler();
-        delay(5);
-    }
-
     i2s_driver_uninstall(I2S_CH);

     pinMode(BOARD_BOOT_PIN, INPUT);
```

Closed 2024-10-02.

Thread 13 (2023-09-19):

UART no longer shows

varna9000, 2023-09-19:
I tried to flash micropython (generic esp32-s3) onthe board, the flashing went well, however UART doesn't show on usb anymore. Any guide how I can I access/enable the usb uart so I can reflash the chip?

varna9000, 2023-09-19:
So I managed to activate the jtag UART (only for flashing) - hold down trabckball button, press reset and release the trackball button. However the normal usb UART still doesn't show after flashing. Is there any specific thing I need to do?

Closed 2024-10-02.

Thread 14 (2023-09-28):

Unable to use the SD Card and display at the same time

technoblogy, 2023-09-28:
I have a T-Deck working nicely with the display, using the **GFX Library for Arduino** by Moon On Our Nation.

I have also got the T-Deck working with the SD Card interface, using the SD library in the ESP32 core, by adding the definition:

    #define SDCARD_SS_PIN 39

and changing the SPI definitions in the file:

/Users/david/Library/Arduino15/packages/esp32/hardware/esp32/2.0.12/variants/esp32s3/pins_arduino.h

to:

    static const uint8_t SS    = 39;
    static const uint8_t MOSI  = 41;
    static const uint8_t MISO  = 38;
    static const uint8_t SCK   = 40;

However, when I use the SD Card the display stops working.

Can anyone provide sample code showing how to use the display and SD Card interface at the same time?

technoblogy, 2023-10-03:
With help from @nanomonkey I have now solved this problem.

Fixed project incorporating this code is here: https://github.com/technoblogy/ulisp-tdeck

Closed 2023-10-03.

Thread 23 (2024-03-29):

Can't compile unit test

lazzaroevan, 2024-03-29:
Using a fresh clone of the repository, I can't build the project with unit test selected. When I do, it says that it is missing

"*** missing SConscript file 'script\\pos_extra_script.py'
File "C:\.platformio\penv\Lib\site-packages\platformio\builder\main.py", line 180, in <module>"

If I try to comment this out, then it says

"xtensa-esp32s3-elf-g++: error: examples/UnitTest/UnitTest.ino.cpp: No such file or directory
xtensa-esp32s3-elf-g++: fatal error: no input files"

Please advise

lewisxhe, 2024-03-29:
remove this line in platformio.ini
```
extra_scripts = script\pos_extra_script.py

```

lazzaroevan, 2024-04-02:
Like I said in my first comment, when I take that line out it errors out with

"xtensa-esp32s3-elf-g++: error: examples/UnitTest/UnitTest.ino.cpp: No such file or directory
xtensa-esp32s3-elf-g++: fatal error: no input files"

lewisxhe, 2024-04-03:
In your case, platformio is not ready yet or the error will be reported after the installation is not completed. Please re-download the warehouse code and reopen it.
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

Closed 2024-09-17.

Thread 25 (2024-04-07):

Antenna connector ripped.

mirkokral, 2024-04-07:
My antenna connector ripped after trying to swap from the default to a better antenna.
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
Is there any way I can reconnect the antenna (original or better) or maybe fix the connector?

Sincerely, Mirko

lewisxhe, 2024-06-19:
The PCB cannot be repaired. You can only solder the antenna directly on the LoRa module.

Closed 2024-09-17.

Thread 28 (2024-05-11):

New T-Deck cannot enter DFU nor gets detected by any computer as USB

SAMGARTNER, 2024-05-11:
Hello, I bought this T-Deck directly at lilygo.cc. I receive it yesterday, I have been trying to flash it but it doesn't respond. There is only a bluelight in the rear and it blinks once when I turn the unit on. I changed cables and used two computer a Macbook and a Windows laptop, none of them detects the USB connection.

As instructed, I keep pressing the scroll wheel button and turn on the unit and then release the button. I also mixed it with the reset button, but nothing happens. Looks bricked

 Is there any other procedure that I should follow?

laulin, 2024-05-18:
Hi SAMGARTNER, I had the same problem as you. I wanted to install mycropython. I did it with the esptool command ( esptool.py --port /dev/ttyACM0 --baud 460800 write_flash -z 0x0 firmware.bin). Hope you find it useful!

acidvegas, 2024-05-26:
> Hi SAMGARTNER, I had the same problem as you. I wanted to install mycropython. I did it with the esptool command ( esptool.py --port /dev/ttyACM0 --baud 460800 write_flash -z 0x0 firmware.bin). Hope you find it useful!

yeah thats not really going to help him here seeing as how its not even detected as a USB device. he wont have /dev/ttyUSB0 or /dev/ttyAMC0

@SAMGARTNER did you happen to power this via battery ever? Or only through the usb cable? I know alot of cheap chinese LiPo batteries have the polarity wrong sometimes....

Closed 2024-09-16.

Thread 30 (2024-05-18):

SD card is not working

laulin, 2024-05-18:
Hello !

I read the pinout from utilities.h and I write a micropython code to mount the SD card :

```
from machine import SPI, Pin
from sdcard import SDCard
import os
import hw

power_en = Pin(hw.PERI_POWERON, mode=Pin.OUT, value=1)

clk = Pin(hw.SPI_SCK, mode=Pin.OUT, value=0) # pin 40
mosi = Pin(hw.SPI_MOSI, mode=Pin.OUT, value=0) # pin 41
miso = Pin(hw.SPI_MISO, mode=Pin.IN) # pin 38
cs_sd = Pin(hw.SDCARD_CS, mode=Pin.OUT, value=1) # pin 39

spi = SPI(1, baudrate=int(hw.SPI_SPEED), sck=clk, mosi=mosi, miso=miso)

try:
    print("SDcard")
    sd = SDCard(spi, cs_sd)
    print("Sdcard mounted")
    os.mount(sd, '/sd')
except Exception as e:
    print(str(e))
```

I always got "OSError: no SD card". The SPI works since I can use the TFT display and I check on the schematic that ESP_SD_CS is on IO39 (real pin : 32).

Do you have any idea ?

contractorwolf, 2024-06-10:
I am having this same issue, cut my code back to barebones but it only says that is doesnt see the sd card.  no damage to the card reader or card.  Card is brand new and FAT32 formatted.

lewisxhe, 2024-06-19:
Refer to the Arduino initialization code, you need to turn on POWERON and disable the CS of other SPI devices.
https://github.com/Xinyuan-LilyGO/T-Deck/blob/36841457bf1c4f9a6e88c9de2199f6ff132885a5/examples/UnitTest/UnitTest.ino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

Closed 2024-09-16.

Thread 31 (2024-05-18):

Hall effect sensor

laulin, 2024-05-18:
Hello,

While I was reading schematic, I discovered four hall effect sensor (UZ1-4, IC : AN4884). I didn't find them on the PCB; I tried to read G_S (Pin 15) with analog pin , played with a magnet over the PCB but nothing. Do you have more infor about these sensors ?

lewisxhe, 2024-06-19:
https://github.com/Xinyuan-LilyGO/T-Deck/blob/36841457bf1c4f9a6e88c9de2199f6ff132885a5/examples/UnitTest/UnitTest.ino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

Closed 2024-09-16.

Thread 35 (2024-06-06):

Can't Compile Unitest in TDeck from Factory - all the steps in the guide completed - Error Compilation error: 'bool enableInterrupt' redeclared as different kind of entity

cmlouro, 2024-06-06:
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

FQBN: esp32:esp32:esp32s3:CDCOnBoot=cdc,FlashSize=16M,PartitionScheme=app3M_fat9M_16MB,PSRAM=opi
Using board 'esp32s3' from platform in folder: C:\Users\carlos.louro\AppData\Local\Arduino15\packages\esp32\hardware\esp32\3.0.0
Using core 'esp32' from platform in folder: C:\Users\carlos.louro\AppData\Local\Arduino15\packages\esp32\hardware\esp32\3.0.0

"@C:\\Users\\carlos.louro\\AppData\\Local\\Arduino15\\packages\\esp32\\tools\\esp32-arduino-libs\\idf-release_v5.1-442a798083/esp32s3/flags/includes" "-IC:\\Users\\carlos.louro\\AppData\\Local\\Arduino15\\packages\\esp32\\tools\\esp32-arduino-libs\\idf-release_v5.1-442a798083/esp32s3/qio_opi/include" "-IC:\\Users\\carlos.louro\\AppData\\Local\\Arduino15\\packages\\esp32\\hardware\\esp32\\3.0.0\\cores\\esp32" "-IC:\\Users\\carlos.louro\\AppData\\Local\\Arduino15\\packages\\esp32\\hardware\\esp32\\3.0.0\\variants\\esp32s3" "-IC:\\Users\\carlos.louro\\AppData\\Local\\Arduino15\\packages\\esp32\\hardware\\esp32\\3.0.0\\libraries\\SPI\\src" "-IC:\\Users\\carlos.louro\\Documents\\Arduino\\libraries\\RadioLib\\src" "-IC:\\Users\\carlos.louro\\Documents\\Arduino\\libraries\\TFT_eSPI" "-IC:\\Users\\carlos.louro\\AppData\\Local\\Arduino15\\packages\\esp32\\hardware\\esp32\\3.0.0\\libraries\\FS\\src" "-IC:\\Users\\carlos.louro\\AppData\\Local\\Arduino15\\packages\\esp32\\hardware\\esp32\\3.0.0\\libraries\\SPIFFS\\src" "-IC:\\Users\\carlos.louro\\Documents\\Arduino\\libraries\\lvgl\\src" "-IC:\\Users\\carlos.louro\\AppData\\Local\\Arduino15\\packages\\esp32\\hardware\\esp32\\3.0.0\\libraries\\SD\\src" "-IC:\\Users\\carlos.louro\\Documents\\Arduino\\libraries\\es7210\\src" "-IC:\\Users\\carlos.louro\\AppData\\Local\\Arduino15\\packages\\esp32\\hardware\\esp32\\3.0.0\\libraries\\Wire\\src" "-IC:\\Users\\carlos.louro\\Documents\\Arduino\\libraries\\ESP32-audioI2S\\src" "-IC:\\Users\\carlos.louro\\AppData\\Local\\Arduino15\\packages\\esp32\\hardware\\esp32\\3.0.0\\libraries\\WiFi\\src" "-IC:\\Users\\carlos.louro\\AppData\\Local\\Arduino15\\packages\\esp32\\hardware\\esp32\\3.0.0\\libraries\\Network\\src" "-IC:\\Users\\carlos.louro\\AppData\\Local\\Arduino15\\packages\\esp32\\hardware\\esp32\\3.0.0\\libraries\\NetworkClientSecure\\src" "-IC:\\Users\\carlos.louro\\AppData\\Local\\Arduino15\\packages\\esp32\\hardware\\esp32\\3.0.0\\libraries\\SD_MMC\\src" "-IC:\\Users\\carlos.louro\\AppData\\Local\\Arduino15\\packages\\esp32\\hardware\\esp32\\3.0.0\\libraries\\FFat\\src" "-IC:\\Users\\carlos.louro\\Documents\\Arduino\\libraries\\TouchLib\\src" "@C:\\Users\\carlos.louro\\AppData\\Local\\Temp\\arduino\\sketches\\86632713314C0D8E57341002A4032628/build_opt.h" "@C:\\Users\\carlos.louro\\AppData\\Local\\Temp\\arduino\\sketches\\86632713314C0D8E57341002A4032628/file_opts" "C:\\Users\\carlos.louro\\AppData\\Local\\Temp\\arduino\\sketches\\86632713314C0D8E57341002A4032628\\sketch\\UnitTest.ino.cpp" -o "C:\\Users\\carlos.louro\\AppData\\Local\\Temp\\arduino\\sketches\\86632713314C0D8E57341002A4032628\\sketch\\UnitTest.ino.cpp.o"
C:\Users\carlos.louro\Downloads\T-Deck-master (1)\T-Deck-master\examples\UnitTest\UnitTest.ino:111:13: error: 'bool enableInterrupt' redeclared as different kind of entity
  111 | bool        enableInterrupt = true;
      |             ^~~~~~~~~~~~~~~
In file included from C:\Users\carlos.louro\AppData\Local\Arduino15\packages\esp32\hardware\esp32\3.0.0\cores\esp32/esp32-hal.h:75,
                 from C:\Users\carlos.louro\AppData\Local\Arduino15\packages\esp32\hardware\esp32\3.0.0\cores\esp32/Arduino.h:36,
                 from C:\Users\carlos.louro\Downloads\T-Deck-master (1)\T-Deck-master\examples\UnitTest\UnitTest.ino:19:
C:\Users\carlos.louro\AppData\Local\Arduino15\packages\esp32\hardware\esp32\3.0.0\cores\esp32/esp32-hal-gpio.h:80:6: note: previous declaration 'void enableInterrupt(uint8_t)'
   80 | void enableInterrupt(uint8_t pin);
      |      ^~~~~~~~~~~~~~~
C:\Users\carlos.louro\Downloads\T-Deck-master (1)\T-Deck-master\examples\UnitTest\UnitTest.ino: In function 'void loopRadio()':
C:\Users\carlos.louro\Downloads\T-Deck-master (1)\T-Deck-master\examples\UnitTest\UnitTest.ino:388:37: error: assignment of function 'void enableInterrupt(uint8_t)'
  388 |                     enableInterrupt = false;
      |                     ~~~~~~~~~~~~~~~~^~~~~~~
C:\Users\carlos.louro\Downloads\T-Deck-master (1)\T-Deck-master\examples\UnitTest\UnitTest.ino:414:37: error: assignment of function 'void enableInterrupt(uint8_t)'
  414 |                     enableInterrupt = true;
      |                     ~~~~~~~~~~~~~~~~^~~~~~
C:\Users\carlos.louro\Downloads\T-Deck-master (1)\T-Deck-master\examples\UnitTest\UnitTest.ino:428:33: error: assignment of function 'void enableInterrupt(uint8_t)'
  428 |                 enableInterrupt = false;
      |                 ~~~~~~~~~~~~~~~~^~~~~~~
C:\Users\carlos.louro\Downloads\T-Deck-master (1)\T-Deck-master\examples\UnitTest\UnitTest.ino:481:33: error: assignment of function 'void enableInterrupt(uint8_t)'
  481 |                 enableInterrupt = true;
      |                 ~~~~~~~~~~~~~~~~^~~~~~
Multiple libraries were found for "SD.h"
  Used: C:\Users\carlos.louro\AppData\Local\Arduino15\packages\esp32\hardware\esp32\3.0.0\libraries\SD
  Not used: C:\Users\carlos.louro\AppData\Local\Arduino15\libraries\SD
Using library SPI at version 2.0.0 in folder: C:\Users\carlos.louro\AppData\Local\Arduino15\packages\esp32\hardware\esp32\3.0.0\libraries\SPI
Using library RadioLib at version 5.3.0 in folder: C:\Users\carlos.louro\Documents\Arduino\libraries\RadioLib
Using library TFT_eSPI at version 2.5.22 in folder: C:\Users\carlos.louro\Documents\Arduino\libraries\TFT_eSPI
Using library FS at version 2.0.0 in folder: C:\Users\carlos.louro\AppData\Local\Arduino15\packages\esp32\hardware\esp32\3.0.0\libraries\FS
Using library SPIFFS at version 2.0.0 in folder: C:\Users\carlos.louro\AppData\Local\Arduino15\packages\esp32\hardware\esp32\3.0.0\libraries\SPIFFS
Using library lvgl at version 8.3.0-dev in folder: C:\Users\carlos.louro\Documents\Arduino\libraries\lvgl
Using library SD at version 2.0.0 in folder: C:\Users\carlos.louro\AppData\Local\Arduino15\packages\esp32\hardware\esp32\3.0.0\libraries\SD
Using library ES7210 at version 1.0 in folder: C:\Users\carlos.louro\Documents\Arduino\libraries\es7210
Using library Wire at version 2.0.0 in folder: C:\Users\carlos.louro\AppData\Local\Arduino15\packages\esp32\hardware\esp32\3.0.0\libraries\Wire
Using library ESP32-audioI2S-master at version 2.0.6 in folder: C:\Users\carlos.louro\Documents\Arduino\libraries\ESP32-audioI2S
Using library WiFi at version 2.0.0 in folder: C:\Users\carlos.louro\AppData\Local\Arduino15\packages\esp32\hardware\esp32\3.0.0\libraries\WiFi
Using library Networking at version 1.0.0 in folder: C:\Users\carlos.louro\AppData\Local\Arduino15\packages\esp32\hardware\esp32\3.0.0\libraries\Network
Using library NetworkClientSecure at version 2.0.0 in folder: C:\Users\carlos.louro\AppData\Local\Arduino15\packages\esp32\hardware\esp32\3.0.0\libraries\NetworkClientSecure
Using library SD_MMC at version 2.0.0 in folder: C:\Users\carlos.louro\AppData\Local\Arduino15\packages\esp32\hardware\esp32\3.0.0\libraries\SD_MMC
Using library FFat at version 2.0.0 in folder: C:\Users\carlos.louro\AppData\Local\Arduino15\packages\esp32\hardware\esp32\3.0.0\libraries\FFat
Using library TouchLib at version 0.0.2 in folder: C:\Users\carlos.louro\Documents\Arduino\libraries\TouchLib
exit status 1

Compilation error: 'bool enableInterrupt' redeclared as different kind of entity

lewisxhe, 2024-06-07:
Downgrade esp32 core 3.0.0 to 2.0.14

aaron-924, 2024-06-07:
now that there is a major release to core 3, can we expect updates in tdeck code to support?

lewisxhe, 2024-06-07:
Not for now, because the upstream TFT_eSPI currently only supports versions below 3.0

cmlouro, 2024-06-07:
> Downgrade esp32 core 3.0.0 to 2.0.14

Thanks will do this

Closed 2024-08-16.

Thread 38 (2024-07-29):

Access IIC Pins

mattcalhoun1, 2024-07-29:
I am looking to port a private mesh communication system over to t-deck (https://chatters.io) and I really need to get an IIC connection (spi would be great too).

Looking at the back of the t-deck, the pinout, and the schematic, it doesn't look to me like there is any exposure of IIC pins on the back of the t-deck. I see 2 very nice uart connections, but not IIC.

I need to add an accurate RTC, as it's critical to the security and a few other core features of the firmware.

Any suggestions, specifically regarding the RTC? I've ordered (not received yet) a couple of different GPS modules with battery backup. I really don't like that solution for a number of reasons, but that's my fallback option.

I'm hoping some easy I2C access is just hiding there somewhere, maybe I can pop off the keyboard and get at them or something, but it's not obvious to me.

I guess I could solder directly to the same pads the esp32 is connected to, but that seems like a bad solution as well.

Thanks

mattcalhoun1, 2024-07-29:
Btw, sorry to open this as an "issue" as it's really just a question, but seems like this is the place to ask

mattcalhoun1, 2024-07-29:
Also looking at hijacking one set of the uart pins with "SoftWire" , we'll see how that goes

lewisxhe, 2024-08-30:
Grove interface can be used as both UART and I2C

Closed 2024-10-15.

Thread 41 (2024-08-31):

Which board should be used for LiliGo T-keyboard

kwccoin, 2024-08-31:
For both PlatformIO and Arduino, you have only

- LilyGo T-DIsplay
- LilyGo T-Dislay-S3

There is no T-keyboard which I believed is C3.  What should I do?

lewisxhe, 2024-08-31:
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

kwccoin, 2024-08-31:
Thanks.  It will be ESP32C3 Dev module.

kwccoin, 2024-08-31:
Strange ... the doc said it is C3 and even the message said it is "Keyboard C3" but I got this error:

A fatal error occurred: This chip is ESP32-S3 not ESP32-C3. Wrong --chip argument?
Failed uploading: uploading error: exit status 2

Also if I do this upload successfully, where to find the LoRa pgm/module/... which is currently running under

lewisxhe, 2024-08-31:
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
Need external USB2TTL to be connected to the programming port instead of TYPE-C

kwccoin, 2024-08-31:
THanks.  How to restore to this LoRA interface after I successfully upload my scratch.  It will replace it I assumed?

I do not find in your example any LoRa interface .ino.

lewisxhe, 2024-08-31:
What is LoRa interface?

kwccoin, 2024-08-31:
It is a module that is optional but installed in my LilyGO-T keyboard.  Mine is 433MHz and the label said

LILYGO
433/470Mhz
Model: LoRa32
SX1262

I believed it is about communication.

kwccoin, 2024-08-31:
> ![image](https://private-user-images.githubusercontent.com/22990954/363386969-2e0ea049-1de0-419a-885b-88cfa707a4af.png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) Need external USB2TTL to be connected to the programming port instead of TYPE-C

Just place order to get those cables ... For the LiliGO LoRa module, how to restore it is still awaiting your answer.  Thanks for the speedy support.

lewisxhe, 2024-08-31:
[UnitTest](https://github.com/Xinyuan-LilyGO/T-Deck/tree/master/examples/UnitTest) contains LoRa examples

Closed 2024-10-16.

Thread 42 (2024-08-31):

T-Deck Plus: possible touch screen hw issue

mverch67, 2024-08-31:
Did you notice that the T-Deck's Plus touch screen is not working as expected? Touched once it delivers I2C touch data for about ten seconds. Reason might be a defective capacitor.

This has been reported for all T-Deck Plus used for the meshtastic project.

lewisxhe, 2024-09-02:
There is a simple hardware test program to test the touch screen before leaving the factory. My test here is that the coordinates will only be reported after pressing. Can you provide the issue link of the report?

lewisxhe, 2024-09-02:
I have received reports from users, but I wrote a simple lvgl sliding example and there is no problem, and I checked the coordinate reporting rate of both screens is 5ms.

You can test this simple example https://github.com/Xinyuan-LilyGO/T-Deck/tree/master/examples/lvgl_example

lewisxhe, 2024-09-02:
I modified the touch driver logic. Here is the demo [video](https://youtu.be/ZwjJLd4vJ2g) and [firmware.factory.zip](https://github.com/user-attachments/files/16833821/firmware.factory.zip)I recorded. You can test it.

RikomagicCloudsto, 2024-09-02:
Thanks, please can you detail the changes you made to the touch driver logic or upload the source so we can incorporate the fix in all versions of T-Deck plus firmware.
Thanks.

lewisxhe, 2024-09-02:
This is where I changed it, which involves changing LovyanGFX. If you don't want to change it, you can change the interrupt pin to -1 when initializing the screen.

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

mverch67, 2024-09-02:
Hi, thanks for the quick reply.
This looks like a workaround for a non-functional TOUCH_INT?
Is there a way to get TOUCH_INT working also?

lewisxhe, 2024-09-04:
Of course, you can use it by modifying the following figure
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

lewisxhe, 2024-09-05:
The root cause of the touch failure is that the old screen is triggered by the falling edge after touching, while the new screen is triggered by the rising edge after touching, which leads to this problem.

Although GT911 can set the interrupt trigger mode, it is invalid on the new screen. I need to communicate with the supplier to see if the trigger mode can be reset.

lewisxhe, 2024-09-10:
@mverch67
Modify the interrupt mode of the screen according to the figure below, so that all GT911 touch screens use a unified interrupt mode, and no other places need to be modified.
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

lewisxhe, 2024-09-11:
The factory report does not match my test results. It is still abnormal after setting. I tested this touch screen alone and the behavior is normal, but the interrupt setting does not seem to have any effect after installing it on T-Deck. I will continue to investigate.

The current solution is to remove the monitoring interrupt first and use the polling register, so that it can be applied to T-Deck and T-Deck-Plus
@mverch67

Achan1125, 2024-09-11:
> I modified the touch driver logic. Here is the demo [video](https://youtu.be/ZwjJLd4vJ2g) and [firmware.factory.zip](https://github.com/user-attachments/files/16833821/firmware.factory.zip) I recorded. You can test it.

Thanks!!!!  I use the other firmware for my 2 T-Deck plus and they all dead!(reboot loop)
( https://github.com/Xinyuan-LilyGO/T-Deck/tree/master/firmware )  <--- Brick for my T-Deck+
but this firmware can work!

mverch67, 2024-09-11:
I figured out, that when touching the screen the T-Deck is pulling the TOUCH_INT GPIO(16) to _low_, but the T-Deck Plus is pulling it _high_. So my current solution to support both variants in a single firmware is to read the GPIO(16) during startup when it is idle and remember this value. Thus, later I can use this value for the TOUCH_INT processing to know if the screen is touched or not.

lewisxhe, 2024-09-13:
@mverch67 I was going in the wrong direction before, it doesn't need to be that complicated
GT911 saves the touch configuration by default, and it only needs to be set once. I reset all the interrupt triggering methods of the touch screen in the factory program of T-Deck, so that the original settings can be overwritten. The mesh firmware does not need to be modified.

The board that had problems before can be flashed with the [UnitTest](https://github.com/Xinyuan-LilyGO/T-Deck/blob/master/firmware/T-Deck_UnitTest_240913.bin) firmware first, and then the meshtastic firmware can be flashed again after the startup is completed, and it can be used normally.

mverch67, 2024-09-30:
I personally don't have have T-Deck plus, but there are reports that your proposal worked. So I think this issue can be closed.

Closed 2024-10-01.

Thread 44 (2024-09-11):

UnitTest.ino.cpp] TypeError : unsupported operand type(s) for -: 'float' and 'NoneType

varlocko, 2024-09-11:
The following occurs

Processing T-Deck-915M (platform: espressif32@6.3.0; board: T-Deck; framework: arduino)
--------------------------------------------------------------------------------------------------------------------------------------------------------------------------------------------------------------------------------
Verbose mode can be enabled via `-v, --verbose` option
CONFIGURATION: https://docs.platformio.org/page/boards/espressif32/T-Deck.html
PLATFORM: Espressif 32 (6.3.0) > LilyGo T-Decl(16M Flash 8M OPI PSRAM )
HARDWARE: ESP32S3 240MHz, 320KB RAM, 16MB Flash
DEBUG: Current (esp-builtin) On-board (esp-builtin) External (cmsis-dap, esp-bridge, esp-prog, iot-bus-jtag, jlink, minimodule, olimex-arm-usb-ocd, olimex-arm-usb-ocd-h, olimex-arm-usb-tiny-h, olimex-jtag-tiny, tumpa)
PACKAGES:
 - framework-arduinoespressif32 @ 3.20009.0 (2.0.9)
 - tool-esptoolpy @ 1.40501.0 (4.5.1)
 - toolchain-riscv32-esp @ 8.4.0+2021r2-patch5
 - toolchain-xtensa-esp32s3 @ 8.4.0+2021r2-patch5
Converting UnitTest.ino
LDF: Library Dependency Finder -> https://bit.ly/configure-pio-ldf
LDF Modes: Finder ~ chain, Compatibility ~ soft
Found 41 compatible libraries
Scanning dependencies...
Dependency Graph
|-- ES7210 @ 1.0.0
|-- TouchLib @ 0.0.2
|-- ESP32-audioI2S @ 2.0.6
|-- lvgl @ 8.3.0-dev
|-- RadioLib @ 5.3.0
|-- SD @ 2.0.0
|-- SPI @ 2.0.0
|-- TFT_eSPI @ 2.5.22
|-- TinyGPSPlus @ 1.0.3
|-- WiFi @ 2.0.0
Building in release mode
******* [examples\UnitTest\UnitTest.ino.cpp] TypeError : unsupported operand type(s) for -: 'float' and 'NoneType'****
================================================================================================= [FAILED] Took 287.41 seconds =================================================================================================

Environment    Status    Duration
-------------  --------  ------------
T-Deck-915M    FAILED    00:04:47.412
============================================================================================ 1 failed, 0 succeeded in 00:04:47.412 ============================================================================================

lewisxhe, 2024-09-12:
This problem seems to be a problem with the platformio environment. You can try compiling an empty sketch.

Closed 2024-10-26.

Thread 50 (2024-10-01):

Reset Cap Touch

mattcalhoun1, 2024-10-01:
Hi, is there a pin mapped for resetting the cap touch for T-Deck? I didn't see a pin mapped, so i also looked for documentation on how to do it via iic, but didn't see that.

I noticed that often after a restart triggered by firmware or triggered by flashing, the touch us unresponsive until i slide the power switch off and back on.

I'm currently working on T-Deck, but will be on t-deck plus very soon, so my question is for both.

Thanks

lewisxhe, 2024-10-01:
There is no reset pin, there is no way to solve this problem, you must power off and restart.

mattcalhoun1, 2024-10-01:
thanks

Closed 2024-10-04.

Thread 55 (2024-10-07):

T-Deck Plus Touch not working

mertensm72, 2024-10-07:
DOA of one of my new T-Decks: Display is functional but touch function does not work.

Is there anything I can do, or do I have to return the device?

lewisxhe, 2024-10-07:
Write the factory test file for testing. If you still cannot touch, take a video and send it to the dealer.

https://github.com/Xinyuan-LilyGO/T-Deck/blob/master/firmware/T-Deck_UnitTest_241004.bin

mertensm72, 2024-10-07:
I already checked that out. The flash file does not start on my T-Deck Plus
Do you have a Manual for flashing the UnitTest to the T-Deck Plus?

lewisxhe, 2024-10-07:
You can check this for the writing method, which is basically the same.
https://github.com/Xinyuan-LilyGO/T-Display-S3/tree/main/firmware

If you cannot write, turn the switch to OFF, then press and hold the button in the middle of the trackball, press it, don't release it, and then turn the switch to ON. At this time, it is in download mode, click Upload, wait for the writing to complete, and press the RST button to restart the device after the writing is completed.

lewisxhe, 2024-10-07:
The write start address is 0, not 0x1000

mertensm72, 2024-10-07:
That worked. But there is no test for touch. Touch also does not work in this testing firmware. I think it's defect

lewisxhe, 2024-10-07:
Shoot a test video and provide it to the dealer, they will process it

mertensm72, 2024-10-07:
I will do so. The dealer is lilygo.cc ;-)

mertensm72, 2024-10-08:
Lewis, would you mind to talk to your sales colleagues, why they don't answer my rma mail request?

lewisxhe, 2024-10-08:
I haven't received their feedback yet. You just need to let them know. Please be patient.

Closed 2024-10-20.

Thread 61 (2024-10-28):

How backlight works on t-deck plus?

bettio, 2024-10-28:
Display backlight (gpio 42) is working on regular t-deck using LEDC PWM , but same code doesn't work with the Plus model.
How backlight can be enabled with esp-idf APIs? Should I use any specific PWM frequency or duty cycle?

lewisxhe, 2024-10-29:
https://github.com/Xinyuan-LilyGO/T-Deck/blob/c43766f13c61b786777405e17fd9e6d6c8bed86c/examples/UnitTest/UnitTest.ino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

bettio, 2024-10-29:
Thanks for the reply, I have 2 more questions: does `setBrightness` works same way on both Plus and non Plus?
Furthermore, I tried to translate it to regular esp-idf code, with no success:
```c
#define BOARD_BL_PIN 42

void setBrightness(uint8_t value)
{
    gpio_set_direction(BOARD_BL_PIN, GPIO_MODE_OUTPUT);

    static uint8_t level = 0;
    static uint8_t steps = 16;
    if (value == 0) {
        gpio_set_level(BOARD_BL_PIN, 0);
        vTaskDelay(3 / portTICK_PERIOD_MS);
        level = 0;
        return;
    }
    if (level == 0) {
        gpio_set_level(BOARD_BL_PIN, 1);
        level = steps;
        delayMicroseconds(30);
    }
    int from = steps - level;
    int to = steps - value;
    int num = (steps + to - from) % steps;
    for (int i = 0; i < num; i++) {
        gpio_set_level(BOARD_BL_PIN, 0);
        gpio_set_level(BOARD_BL_PIN, 1);
    }
    level = value;
}

#define NOP() asm volatile ("nop")

unsigned long IRAM_ATTR micros()
{
    return (unsigned long) (esp_timer_get_time());
}

void IRAM_ATTR delayMicroseconds(uint32_t us)
{
    uint32_t m = micros();
    if(us){
        uint32_t e = (m + us);
        if(m > e){ //overflow
            while(micros() > e){
                NOP();
            }
        }
        while(micros() < e){
            NOP();
        }
    }
}
```

am I missing anything?

lewisxhe, 2024-10-30:
Plus and non-Plus are the same, only the shell and screen are different

I tested it and there was no problem at all
```c
#include <stdio.h>
#include <string.h>
#include <stdlib.h>
#include <inttypes.h>
#include "freertos/FreeRTOS.h"
#include "freertos/task.h"
#include "freertos/queue.h"
#include "driver/gpio.h"
#include "esp_timer.h"
#include <rom/ets_sys.h>
#define BOARD_BL_PIN 42
#define BOARD_POWERON 10

void setBrightness(uint8_t value)
{
    static uint8_t level = 0;
    static uint8_t steps = 16;
    if (value == 0)
    {
        gpio_set_level((gpio_num_t)BOARD_BL_PIN, 0);
        vTaskDelay(pdMS_TO_TICKS(3));
        level = 0;
        return;
    }
    if (level == 0)
    {
        gpio_set_level((gpio_num_t)BOARD_BL_PIN, 1);
        level = steps;
        ets_delay_us(30);
    }
    int from = steps - level;
    int to = steps - value;
    int num = (steps + to - from) % steps;
    for (int i = 0; i < num; i++)
    {
        gpio_set_level((gpio_num_t)BOARD_BL_PIN, 0);
        gpio_set_level((gpio_num_t)BOARD_BL_PIN, 1);
    }
    level = value;
}

void app_main(void)
{

    gpio_config_t config;
    memset(&config, 0, sizeof(config));
    config.pin_bit_mask = 1ULL << BOARD_POWERON;
    config.mode = GPIO_MODE_OUTPUT;
    config.pull_up_en = GPIO_PULLUP_DISABLE;
    config.pull_down_en = GPIO_PULLDOWN_DISABLE;
    config.intr_type = GPIO_INTR_DISABLE;
    ESP_ERROR_CHECK(gpio_config(&config));
    gpio_set_level((gpio_num_t)BOARD_POWERON, 1);

    gpio_config_t bl_pin;
    memset(&bl_pin, 0, sizeof(bl_pin));
    bl_pin.pin_bit_mask = 1ULL << BOARD_BL_PIN;
    bl_pin.mode = GPIO_MODE_OUTPUT;
    bl_pin.pull_up_en = GPIO_PULLUP_DISABLE;
    bl_pin.pull_down_en = GPIO_PULLDOWN_DISABLE;
    bl_pin.intr_type = GPIO_INTR_DISABLE;
    ESP_ERROR_CHECK(gpio_config(&bl_pin));

    uint8_t level = 0;
    while (1)
    {
        setBrightness(level++);
        level %= 16;
        vTaskDelay(1000 / portTICK_PERIOD_MS);
    }
}

```

bettio, 2024-10-30:
Now it works, but there is something that I don't understand yet: how gpio 10 is involved here?
Also it looks required only for the non plus one.

lewisxhe, 2024-11-01:
https://github.com/Xinyuan-LilyGO/T-Deck/blob/c43766f13c61b786777405e17fd9e6d6c8bed86c/examples/UnitTest/UnitTest.ino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

Closed 2024-12-16.

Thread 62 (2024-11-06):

Documentation - Can't Enter Download Mode

AlexBestoso, 2024-11-06:
I've been working with the T-deck for a while and have gotten into a great many boot loops.

Holding down the scroll ball and restarting as described enters me into an invalid upload mode.

I was finally able to get passed this issue by connecting gpio 46 to ground and then repeating the process involving the trackball.

GPIO 46 was the second from the left on the bottom row of esp pinouts.

The above outlined process fixed my issues resulting from serial data corruption due to bad code and should be mentioned in the documentation for trouble shooting flashing issues.

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

lewisxhe, 2024-11-07:
Thanks for the report. This problem is caused by GPIO46 being pulled up to a high level by esp32c3, which makes it impossible to enter USB download mode. The solution is to remove the resistor shown in the figure below.
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

AlexBestoso, 2024-12-19:
I'm not sure if removing the resistor will work or not.

The issue I was having was do to serial corruption due to poor software being flashed.

Which prevented my linux kernel from properly registering the esp device.

I've not tested removing the resistor; but I know for certain that connecting the mentioned pin to ground will work as describe for my particular issue.

This fix here isn't properly documented, so I made this documentation request.

Closed 2025-02-04.

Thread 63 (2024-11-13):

Can't completely load any Audio example

richonguzman, 2024-11-13:
tried using the "Audio.h" for playing a mp3 file through T-deck speaker, but cant find a way to even import libraries needed on platformio to make use of the speaker play.

any small guide as which library to use?

lewisxhe, 2024-11-14:
All examples need to use the library copy in the lib directory

“Audio.h” is here
https://github.com/Xinyuan-LilyGO/T-Deck/tree/master/lib/ESP32-audioI2S

richonguzman, 2024-11-14:
> Copies of all used example libraries are placed in the lib directory
>
> “Audio.h” is here https://github.com/Xinyuan-LilyGO/T-Deck/tree/master/lib/ESP32-audioI2S

should this also work if using Platformio instead of Arduino IDE ?

lewisxhe, 2024-11-14:
Of course it works. There is no difference between the two except the way they are built.

richonguzman, 2024-11-14:
I copy all the "ESP32-audioI2S" folder into /lib folder of my project.

then I compile in Platformio with this:

`
#include "Audio.h"
#include "FS.h"

#ifdef HAS_I2S

    namespace AUDIO_Utils {

        void setup() {
            // nothing yet
        }

    }

#endif`

I get :

/Users/myUserName/.platformio/packages/framework-arduinoespressif32@3.20009.0/libraries/SD_MMC/src/SD_MMC.h:21:10: fatal error: FS.h: No such file or directory

even adding: #include "FS.h" it still get this error and could not go further

lewisxhe, 2024-11-14:
Post your platfromio.ini

richonguzman, 2024-11-14:
[env:ttgo_t_deck_plus]
framework = arduino
monitor_speed = 115200
lib_ldf_mode = deep+
platform = espressif32 @ 6.3.1
board_build.partitions = huge_app.csv
monitor_filters = esp32_exception_decoder
board = esp32-s3-devkitc-1
board_build.mcu = esp32s3
build_flags =
	${common.build_flags}
        -Werror -Wall
	${common.usb_flags}
	-D TTGO_T_DECK_PLUS
	-D BOARD_HAS_PSRAM
	-D HAS_SX1262
	-D GPS_BAUDRATE=38400
	-D HAS_TFT
    -D USER_SETUP_LOADED
    -D ST7789_DRIVER
	-D TFT_WIDTH=240
	-D TFT_HEIGHT=320
    -D TFT_RGB_ORDER=TFT_BGR
    -D TFT_INVERSION_ON
    -D TFT_MISO=38
    -D TFT_MOSI=41
    -D TFT_SCLK=40
    -D TFT_CS=12
    -D TFT_DC=11
    -D TFT_RST=-1
	-D TFT_BUSY=-1
	-D TFT_BL=42
	-D TFT_BACKLIGHT_ON=1
    -D TOUCH_CS=-1
    -D LOAD_GLCD
    -D LOAD_FONT2
    -D LOAD_FONT4
    -D LOAD_FONT6
    -D LOAD_FONT7
    -D LOAD_FONT8
    -D SPI_FREQUENCY=40000000
    -D SPI_READ_FREQUENCY=16000000
lib_deps =
	adafruit/Adafruit BusIO @ 1.16.1
	adafruit/Adafruit Unified Sensor @ 1.1.14
	adafruit/Adafruit BME280 Library @ 2.2.4
	adafruit/Adafruit BMP280 Library @ 2.6.8
	adafruit/Adafruit BME680 Library @ 2.0.4
	bblanchon/ArduinoJson @ 6.21.3
	h2zero/NimBLE-Arduino @ 1.4.1
	jgromes/RadioLib @ 6.6.0
	mathieucarbou/AsyncTCP @ 3.2.5
	mathieucarbou/ESPAsyncWebServer @ 3.2.3
	mikalhart/TinyGPSPlus @ 1.0.3
	paulstoffregen/Time @ 1.6.1
	peterus/esp-logger @ 1.0.0
	shaggydog/OneButton @ 1.5.0
	bodmer/TFT_eSPI @ 2.5.43

lewisxhe, 2024-11-14:
Yours is too complicated, I added a simple playback example

lewisxhe, 2024-11-14:
You can try adding this in lib_deps = esphome/ESP32-audioI2S@2.0.6

richonguzman, 2024-11-14:
> You can try adding this in lib_deps = esphome/ESP32-audioI2S@2.0.6

added "esphome/ESP32-audioI2S @ 2.0.6" in lib_depts (and deleted the other from "/lib")

compiled just to test without adding any more code than before and same:

"In file included from /Users/ricardoguzman/.platformio/packages/framework-arduinoespressif32@3.20009.0/libraries/SD_MMC/src/SD_MMC.cpp:16:
/Users/ricardoguzman/.platformio/packages/framework-arduinoespressif32@3.20009.0/libraries/SD_MMC/src/SD_MMC.h:21:10: fatal error: FS.h: No such file or directory"

#include "FS.h"
          ^~~~~~
compilation terminated.
Compiling .pio/build/ttgo_t_deck_plus/lib735/SPIFFS/SPIFFS.cpp.o
*** [.pio/build/ttgo_t_deck_plus/libabd/SD_MMC/SD_MMC.cpp.o] Error 1

lewisxhe, 2024-11-14:
It seems that there is a problem with the platformio index and it cannot find the correct dependencies.

There is no problem running it alone

richonguzman, 2024-11-14:
> It seems that there is a problem with the platformio index and it cannot find the correct dependencies.
>
> There is no problem running it alone

how could I add this "alone"??

lewisxhe, 2024-11-14:
In my example, it is normal
https://github.com/Xinyuan-LilyGO/T-Deck/commit/7aa23db0230ce803f3efe6043ed15ad7d1eeb431

I was wondering why this avatar looks so familiar, it turns out to be you again. Hahahaha

I just tested it in your project, please fork a fork, comment out the following header file, and it can be compiled normally. This must be caused by a problem with the reference of platformio

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

richonguzman, 2024-11-14:
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

sorry to push so much lately but I'm willing to make lots of upgrades for this!!! 😃

so:
1) library import on platformio.ini is now : esphome/ESP32-audioI2S @ 2.0.7
2) edited the library without "SD_MMC.h" and others.
3) have to add "es7210" folder from T-Deck main to my own /lib

now it can be added a mp3 and plays:

but I have 2 issues:
1) is the quality of the mp3 defined as a minimum to be listened fine?
2) when the board finishes playing the audio it make a noise when it stops

lewisxhe, 2024-11-14:
1. By looking at the source code, we can see that the volume can be set to 0~21
https://github.com/Xinyuan-LilyGO/T-Deck/blob/7aa23db0230ce803f3efe6043ed15ad7d1eeb431/lib/ESP32-audioI2S/src/Audio.cpp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
2. What does it mean when you make a sound when you stop? How do you run it?

richonguzman, 2024-11-14:
> 2. What does it mean when you make a sound when you stop? How do you run it?

`void playMP3(const String& filename) {
            bool findMp3 = false;
            findMp3 = audio.connecttoFS(SPIFFS, filename.c_str());
            if (findMp3) {
                audio.setVolume(21);
                while (audio.isRunning()) {
                    audio.loop();
                //    delay(3);
                }
                /*audio.setVolume(0);
                delay(10);
                audio.stopSong();
                delay(50);*/
                //audio.stop();
            }
        }`

lewisxhe, 2024-11-14:
I didn't notice any popping sounds when I ran it. Does this have anything to do with the audio file?

Closed 2024-12-30.

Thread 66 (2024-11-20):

No gps on the t-deck plus

predictitai, 2024-11-20:
I have bought a T-Deck plus and tried to get the  GPSShield example to work. I notice that the initialization during setup works as intended but i don't receive any location information. All i receive is 'INVALID' and i see 0 satellites are detected. I see locations on my mobile phone so pretty sure there is GPS signal here.

I thought that it had something to do with the radio signal or antenna so i bought a second T-Deck but observed similar issues.
What could I test to see whether there is something wrong with my device or signal?

lewisxhe, 2024-11-21:
If initialization is successful, then there is no problem with communication

1. Is the device placed outdoors?

2. Is the GPS antenna connected reliably?

3. Have you tried to replace the GPS antenna?

predictitai, 2024-11-28:
1. Yes. I get time information meaning that at least it is able to receive a signal.
2. Check that and yes it is connected reliably.
3. I have used a different T-Deck plus unit as I have two with similar results. Change of both being defect is small i suppose.

When i read out the raw commands with the following code:
void loop()
{

    while (SerialGPS.available()) {
        char c = SerialGPS.read();
        Serial.print(c);  // Debugging raw NMEA data
        gps.encode(c);    // Feed character to TinyGPS++
    }

    Serial.print("Satellites: ");
    Serial.println(gps.satellites.value());

    Serial.print("HDOP: ");
    Serial.println(gps.hdop.value());

    delay(1000);
}
I receive the following info:

16:17:29.873 > $GNRMC,,V,,,,,,,,,,N,V*37
16:17:29.874 > $GNVTG,,,,,,,,,N*2E
16:17:29.875 > $GNGGA,,,,,,0,00,99.99,,,,,,*56
16:17:29.876 > $GNGSA,A,1,,,,,,,,,,,,,99.99,99.99,99.99,1*33
16:17:29.878 > $GNGSA,A,1,,,,,,,,,,,,,99.99,99.99,99.99,3*31
16:17:29.880 > $GNGSA,A,1,,,,,,,,,,,,,99.99,99.99,99.99,4*36
16:17:29.881 > $GNGSA,A,1,,,,,,,,,,,,,99.99,99.99,99.99,5*37
16:17:29.883 > $GPGSV,1,1,00,0*65
16:17:29.884 > $GAGSV,1,1,00,0*74
16:17:29.884 > $GBGSV,1,1,00,0*77
16:17:29.885 > $GQGSV,1,1,00,0*64
16:17:29.885 > $GNGLL,,,,,,V,N*7A
16:17:29.886 > Satellites: 0
16:17:29.886 > HDOP: 9999

Any advice or suggestions? I will go outside today and double validate.

predictitai, 2024-11-28:
uint8_t cfg_clear1[] = {0xB5, 0x62, 0x06, 0x09, 0x0D, 0x00, 0xFF, 0xFF, 0x00, 0x00, 0x00, 0x00, 0x00, 0x00, 0x00, 0x00, 0x00, 0x00, 0x02, 0x1C, 0xA2};

    delay(100); // Allow module to stabilize
    SerialGPS.write(cfg_clear1, sizeof(cfg_clear1));
    if (getAck(buffer, 256, 0x05, 0x01)) {
        Serial.println("Get ack successes!");
    }
   Ack does not match for cfg_clear1

lewisxhe, 2024-11-29:
If they do not match, then you should be using the L76K GPS model.

lewisxhe, 2024-11-29:
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

If NMEA sentences are continuously output, it means that the GPS is working. You need to place the device outdoors for testing.

Closed 2025-01-12.

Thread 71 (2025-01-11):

T-deck trackball not working?

asherevan, 2025-01-11:
I am trying to read from the trackball in micropython, but the down direction seems to not work.
I am using this code:

```py
from machine import Pin

pwr = Pin(10, Pin.OUT)
pwr.on()

tb_up = Pin(3, mode=Pin.IN, pull=Pin.PULL_UP)
tb_down = Pin(15, mode=Pin.IN, pull=Pin.PULL_UP)
tb_left = Pin(1, mode=Pin.IN, pull=Pin.PULL_UP)
tb_right = Pin(2, mode=Pin.IN, pull=Pin.PULL_UP)
tb_click = Pin(0, mode=Pin.IN, pull=Pin.PULL_UP)
tb_up_value = tb_up.value()
tb_down_value = tb_down.value()
tb_left_value = tb_left.value()
tb_right_value = tb_right.value()

def left():
    global tb_left_value
    if tb_left.value() != tb_left_value:
        tb_left_value = tb_left.value()
        return True
    else:
        return False

def right():
    global tb_right_value
    if tb_right.value() != tb_right_value:
        tb_right_value = tb_right.value()
        return True
    else:
        return False

def up():
    global tb_up_value
    if tb_up.value() != tb_up_value:
        tb_up_value = tb_up.value()
        return True
    else:
        return False

def down():
    global tb_down_value
    if tb_down.value() != tb_down_value:
        tb_down_value = tb_down.value()
        return True
    else:
        return False

def pressed():
    return not tb_click.value()

while True:
    time.sleep(0.5)
    print('Trackball up:', up(), " Trackball down:", down(), "Trackball right:", right(), " Trackball left:", left(), "Pressed:", pressed())
```

Any ideas?

Also it would be great if you uploaded micropython examples for everything.

asherevan, 2025-01-11:
Also I cannot get the SD card to work.

lewisxhe, 2025-01-13:
You forgot to set GPIO10 high.

asherevan, 2025-01-13:
Oh. Sorry forgot to include that in the code. Updated.

asherevan, 2025-02-06:
Is there a way to fix the SD card problem?

lewisxhe, 2025-02-06:
What happened to the SD card? I thought you had no problem.

asherevan, 2025-02-06:
Oh. Sorry. I had added that in a later comment.
The micro SD card will not mount. I am using a SanDisk 32 GB MicroSD card and using this code:

```python
import machine
import os
import sdcard

sdspi=machine.SoftSPI(-1, sck=machine.Pin(40), mosi=machine.Pin(41), miso=machine.Pin(38, machine.Pin.IN))
sd = sdcard.SDCard(sdspi, machine.Pin(39))
os.mount(sd, '/sd')
print('SD card mounted.')
```

But it randomly returns one of "OSError: no response from SD card",  "OSError: timeout waiting for v2 card", or "OSError: [Errno 19] ENODEV" error.

lewisxhe, 2025-02-07:
The SPI bus is shared by the screen and LoRa. You need to set the SPI CS of the screen and LoRa to HIGH, then perform SD initialization, and set GPIO10 to HIGH. Like this example
https://github.com/Xinyuan-LilyGO/T-Deck/blob/057ad4480ad4995c773434e0aa35a412e44d1b2e/examples/SD/SD.ino#L196

asherevan, 2025-02-07:
Like this?

```python
import machine
from machine import Pin, SoftSPI
import sdcard
import os

pwr = Pin(10)
pwr.on()

sdCS = Pin(39)
screenCS = Pin(12)
loraCS = Pin(9)

screenCS.on()
sdCS.on()
loraCS.on()

MISO = Pin(38, Pin.IN, Pin.PULL_UP)
sdspi=machine.SoftSPI(-1, sck=machine.Pin(40), mosi=machine.Pin(41), miso=MISO)
sd = sdcard.SDCard(sdspi, sdCS)
os.mount(sd, '/sd')
```

lewisxhe, 2025-02-07:
Yes, you try it.

asherevan, 2025-02-07:
I tried it but It still doesn't work.

lewisxhe, 2025-02-08:
Maybe you can try the Arduino code first to test whether the SD card is available. I am not familiar with Micropython.

asherevan, 2025-03-10:
Sorry for the late reply.
I tried the unit test and it seemed to work.

asherevan, 2025-03-15:
I believe that it is a problem with the hardware. Thank you for your help!

Closed 2025-03-15.

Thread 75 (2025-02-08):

LoRa with esp-idf

AkaBkn, 2025-02-08:
I'm currently trying to get the LoRa working. I tried those two libraries together with esp-idf:
- https://github.com/nopnop2002/esp-idf-sx126x
- https://github.com/jgromes/RadioLib

Both giving me SPI errors, or the SX1262 chip behaves strange. Is there something to consider when trying to use those libraries with esp-idf?
Are there some differences between HPD16A and SX1262?

LoRa is working fine with different firmwares.

I tried different things with no luck so far, the first couple of commands over SPI seem to be fine, but then errors occur. here is an example output of the first library:

```
I (277) main_task: Calling app_main()
I (277) RA01S: CONFIG_MISO_GPIO=38
I (277) RA01S: CONFIG_MOSI_GPIO=41
I (277) RA01S: CONFIG_SCLK_GPIO=40
I (287) RA01S: CONFIG_NSS_GPIO=9
I (287) RA01S: CONFIG_RST_GPIO=17
I (287) RA01S: CONFIG_BUSY_GPIO=13
I (287) RA01S: CONFIG_TXEN_GPIO=-1
I (297) RA01S: CONFIG_RXEN_GPIO=-1
I (297) gpio: GPIO[9]| InputEn: 0| OutputEn: 0| OpenDrain: 0| Pullup: 1| Pulldown: 0| Intr:0
I (307) gpio: GPIO[17]| InputEn: 0| OutputEn: 0| OpenDrain: 0| Pullup: 1| Pulldown: 0| Intr:0
I (317) gpio: GPIO[13]| InputEn: 0| OutputEn: 0| OpenDrain: 0| Pullup: 1| Pulldown: 0| Intr:0
I (327) RA01S: spi_bus_initialize=0
I (327) RA01S: spi_bus_add_device=0
I (327) MAIN: Frequency is 866MHz
W (337) MAIN: Enable TCXO
I (337) MAIN: LoRa Begin
I (377) RA01S: ReadRegister: REG=0x740
I (377) RA01S: DataIn:14
I (377) RA01S: DataIn:24
I (377) RA01S: syncWord=0x1424
I (377) RA01S: SX126x installed
I (377) RA01S: WriteCommand: CMD=0x80 [1]
I (387) RA01S: 00 --> aa
W (387) RA01S: WriteCommand2 status=0a retry=1
I (387) RA01S: WriteCommand: CMD=0x80 [1]
I (397) RA01S: 00 --> a2
I (397) RA01S: WriteCommand: CMD=0x9d [1]
I (397) RA01S: 01 --> 00
W (407) RA01S: WriteCommand2 status=ff retry=1
I (407) RA01S: WriteCommand: CMD=0x9d [1]
I (407) RA01S: 01 --> aa
W (417) RA01S: WriteCommand2 status=0a retry=2
I (417) RA01S: WriteCommand: CMD=0x9d [1]
I (417) RA01S: 01 --> a8
W (427) RA01S: WriteCommand2 status=08 retry=3
I (427) RA01S: WriteCommand: CMD=0x9d [1]
I (427) RA01S: 01 --> a2
I (437) RA01S: tcxoVoltage=1.600000
I (437) RA01S: WriteCommand: CMD=0x97 [4]
I (437) RA01S: 00 --> a2
I (437) RA01S: 00 --> 00
W (447) RA01S: WriteCommand2 status=ff retry=1
I (447) RA01S: WriteCommand: CMD=0x97 [4]
I (447) RA01S: 00 --> aa
W (457) RA01S: WriteCommand2 status=0a retry=2
I (457) RA01S: WriteCommand: CMD=0x97 [4]
I (467) RA01S: 00 --> a2
I (467) RA01S: 00 --> a2
I (467) RA01S: 01 --> a2
I (467) RA01S: 40 --> 00
W (477) RA01S: WriteCommand2 status=ff retry=3
I (477) RA01S: WriteCommand: CMD=0x97 [4]
I (477) RA01S: 00 --> aa
W (477) RA01S: WriteCommand2 status=0a retry=4
I (487) RA01S: WriteCommand: CMD=0x97 [4]
I (487) RA01S: 00 --> a2
I (487) RA01S: 00 --> a2
I (497) RA01S: 01 --> a2
I (497) RA01S: 40 --> 00
W (497) RA01S: WriteCommand2 status=ff retry=5
I (507) RA01S: WriteCommand: CMD=0x97 [4]
I (507) RA01S: 00 --> aa
W (507) RA01S: WriteCommand2 status=0a retry=6
I (517) RA01S: WriteCommand: CMD=0x97 [4]
I (517) RA01S: 00 --> a2
I (517) RA01S: 00 --> a2
I (517) RA01S: 01 --> a2
I (527) RA01S: 40 --> 00
W (527) RA01S: WriteCommand2 status=ff retry=7
I (527) RA01S: WriteCommand: CMD=0x97 [4]
I (537) RA01S: 00 --> aa
W (537) RA01S: WriteCommand2 status=0a retry=8
I (537) RA01S: WriteCommand: CMD=0x97 [4]
I (547) RA01S: 00 --> a2
I (547) RA01S: 00 --> a2
I (547) RA01S: 01 --> a2
I (547) RA01S: 40 --> 00
W (557) RA01S: WriteCommand2 status=ff retry=9
E (557) RA01S: SPI Transaction error:0xff
```

What are the correct settings? LDO, TXO

lewisxhe, 2025-02-10:
You didn't tell me which board it was.

AkaBkn, 2025-02-10:
I'm developing for the T-Deck Plus.

lewisxhe, 2025-02-10:
1. Is GPIO10 set to high level?
2. Is CS set to high level for shared SPI bus, screen, SD card?

lewisxhe, 2025-02-10:
There are many open source examples of t-deck in the community, such as this one https://github.com/ByteWelder/Tactility

AkaBkn, 2025-02-10:
1. Yes, GPIO10 is HIGH (but thats `BOARD_POWERON`)
2. Yes, CS for RADIO is LOW during SPI transaction, otherwise all CS (radio, screen, sdcard) are HIGH
3. There are some open source examples, but I couldn't find one using LoRa on esp-idf. The one you sent doesn't even use LoRa
4. Is this corect?
```
I (277) RA01S: CONFIG_MISO_GPIO=38
I (277) RA01S: CONFIG_MOSI_GPIO=41
I (277) RA01S: CONFIG_SCLK_GPIO=40
I (287) RA01S: CONFIG_NSS_GPIO=9
I (287) RA01S: CONFIG_RST_GPIO=17
I (287) RA01S: CONFIG_BUSY_GPIO=13
```
5. Are there some differences between HPD16A and SX1262?

lewisxhe, 2025-02-10:
HPD16A Which one do you mean? Any pictures?
You configured the IO correctly, but you didn't configure DIO1 = 45

AkaBkn, 2025-02-10:
HPDA16A: I have no idea, but that is the name in the schematic (https://github.com/Xinyuan-LilyGO/T-Deck/blob/master/schematic/schematic.pdf)

DIO1: As far as i know, its only used when configured by the radio, it can have different purposes like IRQ. But it should not be needed for basic usage, am I right?

lewisxhe, 2025-02-10:
T-deck only has SX1262 version. TCXO 3.3V, LDO does not need to be set.

lewisxhe, 2025-02-10:
There is nothing special to note, everything is normal
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

lewisxhe, 2025-02-10:
```c
/* The example of ESP-IDF
 *
 * This sample code is in the public domain.
 */

#include <stdio.h>
#include <inttypes.h>
#include <string.h>

#include "freertos/FreeRTOS.h"
#include "freertos/task.h"
#include "esp_log.h"
#include <driver/gpio.h>
#include "ra01s.h"

static const char *TAG = "MAIN";

#if CONFIG_SENDER
void task_tx(void *pvParameters)
{
	ESP_LOGI(pcTaskGetName(NULL), "Start");
	uint8_t buf[256]; // Maximum Payload size of SX1261/62/68 is 255
	while(1) {
		TickType_t nowTick = xTaskGetTickCount();
		int txLen = sprintf((char *)buf, "Hello World %"PRIu32, nowTick);
		ESP_LOGI(pcTaskGetName(NULL), "%d byte packet sent...", txLen);

		// Wait for transmission to complete
		if (LoRaSend(buf, txLen, SX126x_TXMODE_SYNC) == false) {
			ESP_LOGE(pcTaskGetName(NULL),"LoRaSend fail");
		}

		// Do not wait for the transmission to be completed
		//LoRaSend(buf, txLen, SX126x_TXMODE_ASYNC );

		int lost = GetPacketLost();
		if (lost != 0) {
			ESP_LOGW(pcTaskGetName(NULL), "%d packets lost", lost);
		}

		vTaskDelay(pdMS_TO_TICKS(1000));
	} // end while
}
#endif // CONFIG_SENDER

#if CONFIG_RECEIVER
void task_rx(void *pvParameters)
{
	ESP_LOGI(pcTaskGetName(NULL), "Start");
	uint8_t buf[256]; // Maximum Payload size of SX1261/62/68 is 255
	while(1) {
		uint8_t rxLen = LoRaReceive(buf, sizeof(buf));
		if ( rxLen > 0 ) {
			ESP_LOGI(pcTaskGetName(NULL), "%d byte packet received:[%.*s]", rxLen, rxLen, buf);

			int8_t rssi, snr;
			GetPacketStatus(&rssi, &snr);
			ESP_LOGI(pcTaskGetName(NULL), "rssi=%d[dBm] snr=%d[dB]", rssi, snr);
		}
		vTaskDelay(1); // Avoid WatchDog alerts
	} // end while
}
#endif // CONFIG_RECEIVER

void app_main()
{
	gpio_reset_pin(10);
	gpio_set_direction(10, GPIO_MODE_OUTPUT);
	gpio_set_level(10, 1);

	gpio_reset_pin(12);
	gpio_set_direction(12, GPIO_MODE_OUTPUT);
	gpio_set_level(12, 1);

	gpio_reset_pin(39);
	gpio_set_direction(39, GPIO_MODE_OUTPUT);
	gpio_set_level(39, 1);

	// Initialize LoRa
	LoRaInit();
	int8_t txPowerInDbm = 22;

	uint32_t frequencyInHz = 0;
#if CONFIG_433MHZ
	frequencyInHz = 433000000;
	ESP_LOGI(TAG, "Frequency is 433MHz");
#elif CONFIG_866MHZ
	frequencyInHz = 866000000;
	ESP_LOGI(TAG, "Frequency is 866MHz");
#elif CONFIG_915MHZ
	frequencyInHz = 915000000;
	ESP_LOGI(TAG, "Frequency is 915MHz");
#elif CONFIG_OTHER
	ESP_LOGI(TAG, "Frequency is %dMHz", CONFIG_OTHER_FREQUENCY);
	frequencyInHz = CONFIG_OTHER_FREQUENCY * 1000000;
#endif

#if CONFIG_USE_TCXO
	ESP_LOGW(TAG, "Enable TCXO");
	float tcxoVoltage = 3.3; // use TCXO
	bool useRegulatorLDO = true; // use DCDC + LDO
#else
	ESP_LOGW(TAG, "Disable TCXO");
	float tcxoVoltage = 0.0; // don't use TCXO
	bool useRegulatorLDO = false; // use only LDO in all modes
#endif

	//LoRaDebugPrint(true);
	if (LoRaBegin(frequencyInHz, txPowerInDbm, tcxoVoltage, useRegulatorLDO) != 0) {
		ESP_LOGE(TAG, "Does not recognize the module");
		while(1) {
			vTaskDelay(1);
		}
	}

	uint8_t spreadingFactor = 7;
	uint8_t bandwidth = 4;
	uint8_t codingRate = 1;
	uint16_t preambleLength = 8;
	uint8_t payloadLen = 0;
	bool crcOn = true;
	bool invertIrq = false;
#if CONFIG_ADVANCED
	spreadingFactor = CONFIG_SF_RATE;
	bandwidth = CONFIG_BANDWIDTH;
	codingRate = CONFIG_CODING_RATE;
#endif
	LoRaConfig(spreadingFactor, bandwidth, codingRate, preambleLength, payloadLen, crcOn, invertIrq);

#if CONFIG_SENDER
	xTaskCreate(&task_tx, "TX", 1024*4, NULL, 5, NULL);
#endif
#if CONFIG_RECEIVER
	xTaskCreate(&task_rx, "RX", 1024*4, NULL, 5, NULL);
#endif
}

```

AkaBkn, 2025-02-10:
yes, it works now! Thanks for your help!

I missed the `gpio_set_direction(x, GPIO_MODE_OUTPUT);`. so I guess the level was never set and thus the SPI errors.

so for conclusion:

```
gpio_reset_pin(BOARD_POWERON);
gpio_set_direction(BOARD_POWERON, GPIO_MODE_OUTPUT);
gpio_set_level(BOARD_POWERON, 1);

gpio_reset_pin(BOARD_TFT_CS);
gpio_set_direction(BOARD_TFT_CS, GPIO_MODE_OUTPUT);
gpio_set_level(BOARD_TFT_CS, 1);

gpio_reset_pin(BOARD_SDCARD_CS);
gpio_set_direction(BOARD_SDCARD_CS, GPIO_MODE_OUTPUT);
gpio_set_level(BOARD_SDCARD_CS, 1);
```

```
CONFIG_MISO_GPIO=38
CONFIG_MOSI_GPIO=41
CONFIG_SCLK_GPIO=40
CONFIG_NSS_GPIO=9
CONFIG_RST_GPIO=17
CONFIG_BUSY_GPIO=13

CONFIG_USE_TCXO=1
```

Closed 2025-02-10.

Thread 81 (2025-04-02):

error in compiling the UnitTest example: macro not declared

jimyuill, 2025-04-02:
There's an error in compiling the UnitTest example:
T-Deck/examples/UnitTest /UnitTest.ino

I'm using package ESP32 version 2.0.14, per the T-Deck installation instructions

When compiling the UnitTest example, I get this error:
C:\Arduino\repos\T-Deck\examples\UnitTest\UnitTest.ino:274:27: error: 'WIFI_PASSWORD' was not declared in this scope

Apparently, "WIFI_PASSWORD" is a typo.
And, it should be "WIFI_PASS", as declared in config.h

lewisxhe, 2025-04-07:
Already modified, thanks for the report

Closed 2025-05-21.

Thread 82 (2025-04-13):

PlatformIO: Unable to Build UnitTest, FreeRTOS Not Found Errors

kneave, 2025-04-13:
Hi,

I've followed the steps in the readme to open the project in Visual Studio Code and I'm unable to build the UnitTest example.
The errors seem to suggest some dependencies aren't being met but I'm not sure how to install them or what is missing.

Any advice would be greatly received!

```

Processing T-Deck (platform: espressif32@6.3.0; board: T-Deck; framework: arduino)
------------------------------------------------------------------------------------------------------------------------------------------------------------------
Verbose mode can be enabled via `-v, --verbose` option
CONFIGURATION: https://docs.platformio.org/page/boards/espressif32/T-Deck.html
PLATFORM: Espressif 32 (6.3.0) > LilyGo T-Decl(16M Flash 8M OPI PSRAM )
HARDWARE: ESP32S3 240MHz, 320KB RAM, 16MB Flash
DEBUG: Current (esp-builtin) On-board (esp-builtin) External (cmsis-dap, esp-bridge, esp-prog, iot-bus-jtag, jlink, minimodule, olimex-arm-usb-ocd, olimex-arm-usb-ocd-h, olimex-arm-usb-tiny-h, olimex-jtag-tiny, tumpa)
PACKAGES:
 - framework-arduinoespressif32 @ 3.20009.0 (2.0.9)
 - tool-esptoolpy @ 1.40501.0 (4.5.1)
 - toolchain-riscv32-esp @ 8.4.0+2021r2-patch5
 - toolchain-xtensa-esp32s3 @ 8.4.0+2021r2-patch5
Converting UnitTest.ino
LDF: Library Dependency Finder -> https://bit.ly/configure-pio-ldf
LDF Modes: Finder ~ chain, Compatibility ~ soft
Found 43 compatible libraries
Scanning dependencies...
Dependency Graph
|-- ES7210 @ 1.0.0
|-- SensorLib @ 0.2.0
|-- ESP32-audioI2S @ 2.0.6
|-- lvgl @ 8.4.0
|-- RadioLib @ 7.1.0
|-- SD @ 2.0.0
|-- SPI @ 2.0.0
|-- TFT_eSPI @ 2.5.43
|-- TinyGPSPlus @ 1.0.3
|-- WiFi @ 2.0.0
Building in release mode
Compiling .pio\build\T-Deck\src\UnitTest.ino.cpp.o
Compiling .pio\build\T-Deck\src\src\image_emoji.c.o
Compiling .pio\build\T-Deck\src\src\logo_font.c.o
Compiling .pio\build\T-Deck\src\src\wallpaper.c.o
Compiling .pio\build\T-Deck\src\ui.cpp.o
*** [.pio\build\T-Deck\bootloader.bin] Source `C:\Users\keegan\.platformio\packages\framework-arduinoespressif32@3.20009.0\tools\sdk\esp32s3\bin\bootloader_qio_80m.elf' not found, needed by target `.pio\build\T-Deck\bootloader.bin'.
In file included from C:\Users\keegan\AppData\Local\Temp\tmpdbrh2259:1:
C:/Users/keegan/.platformio/packages/framework-arduinoespressif32@3.20009.0/cores/esp32/Arduino.h:33:10: fatal error: freertos/FreeRTOS.h: No such file or directory
 #include "freertos/FreeRTOS.h"
          ^~~~~~~~~~~~~~~~~~~~~
compilation terminated.
*** [.pio\build\T-Deck\src\UnitTest.ino.cpp.o] Error 1
In file included from examples/UnitTest/ui.cpp:10:
C:/Users/keegan/.platformio/packages/framework-arduinoespressif32@3.20009.0/cores/esp32/Arduino.h:33:10: fatal error: freertos/FreeRTOS.h: No such file or directory
 #include "freertos/FreeRTOS.h"
          ^~~~~~~~~~~~~~~~~~~~~
compilation terminated.
*** [.pio\build\T-Deck\src\ui.cpp.o] Error 1
In file included from lib/lvgl/src/misc/../lv_conf_internal.h:15,
                 from lib/lvgl/src/misc/lv_log.h:16,
                 from lib/lvgl/lvgl.h:25,
                 from examples/UnitTest/src/logo_font.c:5:
lib/lvgl/src/misc/../lv_conf_kconfig.h:15:14: fatal error: sdkconfig.h: No such file or directory

*******************************************************************
* Looking for sdkconfig.h dependency? Check our library registry!
*
* CLI  > platformio lib search "header:sdkconfig.h"
* Web  > https://registry.platformio.org/search?q=header:sdkconfig.h
*
*******************************************************************

 #    include "sdkconfig.h"
              ^~~~~~~~~~~~~
compilation terminated.
In file included from lib/lvgl/src/misc/../lv_conf_internal.h:15,
                 from lib/lvgl/src/misc/lv_log.h:16,
                 from lib/lvgl/lvgl.h:25,
                 from examples/UnitTest/src/image_emoji.c:10:
lib/lvgl/src/misc/../lv_conf_kconfig.h:15:14: fatal error: sdkconfig.h: No such file or directory

*******************************************************************
* Looking for sdkconfig.h dependency? Check our library registry!
*
* CLI  > platformio lib search "header:sdkconfig.h"
* Web  > https://registry.platformio.org/search?q=header:sdkconfig.h
*
*******************************************************************

 #    include "sdkconfig.h"
              ^~~~~~~~~~~~~
compilation terminated.
*** [.pio\build\T-Deck\src\src\image_emoji.c.o] Error 1
*** [.pio\build\T-Deck\src\src\logo_font.c.o] Error 1
In file included from lib/lvgl/src/misc/../lv_conf_internal.h:15,
                 from lib/lvgl/src/misc/lv_log.h:16,
                 from lib/lvgl/lvgl.h:25,
                 from examples/UnitTest/src/wallpaper.c:2:
lib/lvgl/src/misc/../lv_conf_kconfig.h:15:14: fatal error: sdkconfig.h: No such file or directory

*******************************************************************
* Looking for sdkconfig.h dependency? Check our library registry!
*
* CLI  > platformio lib search "header:sdkconfig.h"
* Web  > https://registry.platformio.org/search?q=header:sdkconfig.h
*
*******************************************************************

 #    include "sdkconfig.h"
              ^~~~~~~~~~~~~
compilation terminated.
*** [.pio\build\T-Deck\src\src\wallpaper.c.o] Error 1
================================================================== [FAILED] Took 10.72 seconds ==================================================================

Environment    Status    Duration
-------------  --------  ------------
T-Deck         FAILED    00:00:10.723
============================================================= 1 failed, 0 succeeded in 00:00:10.723 =============================================================

```

lewisxhe, 2025-04-14:
This error should be that your platformio esp32 package is not installed completely, delete .platformio and reinstall it

kneave, 2025-05-15:
> This error should be that your platformio esp32 package is not installed completely, delete .platformio and reinstall it

That worked, thanks!

Closed 2025-05-15.

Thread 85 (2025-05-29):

TFT display datasheet / problem

omikron88, 2025-05-29:
Hello,
May you public the datasheet of the TFT display used currently?
I am still having some troubles in Arduino IDE. It reboots during tft.begin()

omikron88, 2025-05-30:
Yes, but it still reboots in begin, even if provider eTFT copied into
library folder.

Dne pá 30. 5. 2025 9:23 uživatel Lewis He ***@***.***> napsal:

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

lewisxhe, 2025-06-03:
Restarting when calling tft.begin only happens when the pin assignment is wrong. Are you sure that restarting occurs when calling tft.begin ? What if you do something else instead of calling tft.begin ? For example, print hello ?

Closed 2025-07-17.

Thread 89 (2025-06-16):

I think my tdeck is defective and your support chat won't work

framerate, 2025-06-16:
Order LILYGO-47827

My TDeck cannot connect to any nodes. I have a heltec v3 here connecting to tons with a smaller antennae. I tested with the included antennae and a much larger one and I cannot connect to any nodes. I think maybe the antennae connector or radio chip is defective.

I've also flashed the latest meshtastic firmware so I've ruled out its a meshtastic problem and appears to be a hardware problem

Please let me know how to file a RMA.

lewisxhe, 2025-06-18:
Here, select the T-Deck_UnitTest_241220.bin file and write it according to the method in README. Switch RX and TX in the radio interface. Normally, TX should be valid in the state of a single node, and RX requires two nodes with the same settings.
https://github.com/Xinyuan-LilyGO/T-Deck/tree/master/firmware

lewisxhe, 2025-06-21:
It looks like the radio is working fine. I even suspect that LilyGo sent you the wrong frequency. The frequency should be marked on your packaging shell and antenna. What is written on it?

You can also remove the shell of the t-deck, and the radio module inside also has the frequency marked on it.

framerate, 2025-06-23:
Its not the plus, so its the board only. The radio is marked 868/915mhz, which I believe is correct? I have an external antennae attached as well for 915Mhz.

Please advise, I don't know how to reach out other than this github thread to get this replaced. (PS I have a TDeck Plus coming today or tomorrow so I can compare reception as well)

framerate, 2025-06-30:
@lewisxhe I solved this problem. On the Meshtastic discord, they told me there's a known issue with the latest firmware(s) that its not setting the default channel when you flash the firmware.

I think its setting channel 0 and you have to set channel 20 manually. Then it starts to work (in case someone else reports this)

lewisxhe, 2025-07-01:
Yes, someone has reported this issue to me. Thanks for your answer.

Closed 2025-06-30.

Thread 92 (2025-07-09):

Still Cant Rx or TX

MikeMesh, 2025-07-09:
Greetings,

fired up a brand new Tdeck plus today. Wont talk to other nodes. Discovered the channel issue, changed slot to 20, freq moved to 906.875 as its supposed to. Reflashed firmware, factory resets, nothing. Still no go.

But none of that solved the issue. I have many other nodes so I am knowledgeable and familiar with meshtastic, but I cant make this one talk.

I can see it transmitting on a spectrum analyzer but nothing understands it and it understands no other nodes.

Ive tried the public channel, custom channels, removing encryption, but nothing works.

Any advice would be greatly welcomed.

Cheers

MikeMesh, 2025-07-09:
I cant guess whats going on. Yes my problem is similar to that of 89, but changing the freq slot to 20 did not solve it. Nor did reflashing of resetting the firmware. I even back up to one older firmware and tried it. Still no go. Ive done just about everything I can think of. I am starting to suspect there may be an issue with the sx1262 radio. I have tried every setting. I so wanted this to go. This is a great looking package!

lewisxhe, 2025-07-09:
OK! I need @mverch67 's advice

MikeMesh, 2025-07-09:
Thank you. Its 11:30 at night here and i got work tomorrow. So im off to get some sleep. I shall return around 7 pm EST.

Cheers and thank you again.

MikeMesh, 2025-07-09:
oh, everything else works fine. the screen, the menus etc. I see no issues here.

mverch67, 2025-07-09:
@MikeMesh
> I can see it transmitting on a spectrum analyzer but nothing understands it and it understands no other nodes.

How do you determine _"nothing understands it"_? Did you look into the USB serial debug log? When sending and receiving you always see detailed information that clearly gives you a hint what went wrong, e.g. here a packet is received but cannot be decoded:

```
DEBUG | ??:??:?? 77 [RadioIf] Lora RX (id=0x39dc4642 fr=0x17173035 to=0xffffffff, WantAck=0, HopLim=2 Ch=0x1e encrypted len=50 rxSNR=6.75 rxRSSI=-65 hopStart=7 relay=0xdc)
DEBUG | ??:??:?? 77 [RadioIf] Packet RX: 608ms
INFO  | ??:??:?? 77 [Router] Packet History - insert: Using new slot @uptime 77.676s TRACE NEW
WARN  | ??:??:?? 77 [Router] No suitable channel found for decoding, hash was 0x1e!
DEBUG | ??:??:?? 77 [Router] packet decoding failed or skipped (no PSK?) (id=0x39dc4642 fr=0x17173035 to=0xffffffff, WantAck=0, HopLim=2 Ch=0x1e encrypted len=50 rxSNR=6.75 rxRSSI=-65 hop
```

MikeMesh, 2025-07-09:
[meshtastic_debug_20250709_070405.log](https://github.com/user-attachments/files/21141157/meshtastic_debug_20250709_070405.log)

See the attached file. the unit does not see other nodes, other nodes do not see it.

mverch67, 2025-07-10:
LoRa works fine! This is your issue:

`WARN | 00:10:56 141 [Router] No suitable channel found for decoding, hash was 0xa!`

mverch67, 2025-07-10:
> They are matched. Perfectly. AQ==

Do you have proof? Screenshot, export-config, etc. will do.

mverch67, 2025-07-10:
What device is that? The T-Deck? What about the other device?

MikeMesh, 2025-07-10:
> What device is that? The T-Deck? What about the other device?

Yes, all the other devices are EXACLTY the same. All the other devices are communicating. The screen shot I sent you is the T deck plus, the problem device.
They are ALL the same. 7 of them. All in close proximity. All work except the Tdeck plus

ALL LongFast AQ==

mverch67, 2025-07-10:
Did you type in the "LongFast"? Usually for the default channel it should be kept blank, so that when changing the preset (e.g. to MediumFast) the UI can replace the channel name according to the chosen preset.

MikeMesh, 2025-07-10:
> Did you type in the "LongFast"? Usually for the default channel it should be kept blank, so that when changing the preset (e.g. to MediumFast) the UI can replace the channel name according to the chosen preset.

I have tried this no less than 3 ways several times.

1) I went with what the firmware was preprogrammed with for primary channel. Didnt work. I have never had a preprogrammed primary channel fail to work till now.
2) I re-entered manually LongFast and AQ==. Didnt work.
3) I left the primary channel blank with AQ== psk. Didnt work.
4) I entered my private channel and psk, which operates and shared with many other nodes and for the T deck plus, it didnt work.
5) when i make these changes, I reboot the device and ensure my settings were in place. I have programmed over 40 of these nodes, so I have some fairly good experience in doing so.
6) I have tried the above with no encryption. It didnt work.

Notes.

All of the above has been tried and check several times with no results. I reinstalled the firmware thinking it might have been a bad flash.
I went thru the above drill again. It didnt work.
Keep in mind in the LoRa section, I had to change the slot number to 20 and I also ensured the unit was transmitting centered on 906.875.
I installed older firmware and did all the tests again. It didnt work. I also checked and ensured the slot freq was correct.
Since then I have reinstalled the latest firmware, changed the slot to 20 and tried the above again. It didnt work.

MikeMesh, 2025-07-10:
> What you could try is use a different preset with a lower spreading factor (SF) to see if it's the LoRa radio that has difficulties at SF11 (see https://meshtastic.org/docs/overview/radio-settings/#presets). I.e. set the T-Deck and another device to e.g. MediumFast and then see if they hear each other or still have this decode issue.

I set up a test to do this.

1)Installed fresh firmware on the Tdeck Plus. Configured the Region, gave it a fast name and changed the slot freq to 20. Confirmed transmit at 906.875.  Added my private channel and psk as well. Two channels showing. The primary LongFast and my private channel. Confirmed all psks are correct.
2) set the modem to Long_Slow.
3) I set one V3, One T114 and a RAK 19007 all to Long_Slow. They are share the same channels and I tested them all at this speed rate. All of these radios listed here connected to each other without issue.
4) The Tdeck did not connect. It did not work.

MikeMesh, 2025-07-11:
> OK. I have seen the above message. I apply to send you a new device. As for the device in question, let's see if it can be sent back to us. I have seen your message on the customer service platform.

@lewisxhe

Thank you. I cant stress how important this is. It all needs to happen very fast.

mverch67, 2025-07-11:
@MikeMesh
> 3) I set one V3, One T114 and a RAK 19007 all to Long_Slow. They are share the same channels and I tested them all at this speed rate. All of these radios listed here connected to each other without issue.

LongSlow is the wrong test because it is SF12. If the radio has problems with SF11 it will probably also not work on SF12. My request was to test lower spreading factors (see https://meshtastic.org/docs/overview/radio-settings/#presets) like MediumFast (SF9).

Then, can you also test with the latest firmware. It solved the channel 1 -> 20 issue. Then only set region and give it short/long name in the initial popup dialog and reboot. No further channel settings, keep all default(!).

MikeMesh, 2025-07-11:
@mverch67

I see no new firmware. Only 2.6.11. This is what I  am running. It has the error in it.

I do not have Python CLI set up yet. Its on my list of things to do, but not today.

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

MikeMesh, 2025-07-11:
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

The other nodes dont see it or show in their respective nodes list. its been running for hours now.

mverch67, 2025-07-11:
> The other nodes dont see it or show in their respective nodes list. its been running for hours now.

I mean what do they write into their debug log?

mverch67, 2025-07-11:
Do they write this line (**hash was 0x8**) or what is their hash code they'd complain about?

`WARN | ??:??:?? 47 [Router] No suitable channel found for decoding, hash was 0x8!`

mverch67, 2025-07-11:
> Heres a look at the log, same error. I fully believe there is a hardware issue with the radio.

Not very likely because all other packet data looks correct (and the chip has error correction) except the hash code. Which lets assume the error is due to different channel config at sending/receiving node.

MikeMesh, 2025-07-11:
DEBUG | 18:05:59 60085 [Router] packet decoding failed or skipped (no PSK?) (id=0x6a5946ba fr=0xa0a9ed78 to=0xffffffff, WantAck=0, HopLim=3 Ch=0x8 encrypted len=48 rxtime=1752257159 rxSNR=6.

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

mverch67, 2025-07-11:
I just checked on my T-Deck: I've set it to US/20/906.875 and see the following in the log:

```
DEBUG | ??:??:?? 166 [RadioIf] Started Tx (id=0x9f915589 fr=0x99bc689c to=0xffffffff, WantAck=0, HopLim=3 **Ch=0x8** encrypted len=113 hopStart=3 relay=0x9c priority=64)
DEBUG | ??:??:?? 166 [RadioIf] Packet TX: 1075ms
DEBUG | ??:??:?? 166 [RadioIf] 0 packets remain in the TX queue
DEBUG | ??:??:?? 167 [RadioIf] Completed sending (id=0x9f915589 fr=0x99bc689c to=0xffffffff, WantAck=0, HopLim=3 Ch=0x8 encrypted len=113 hopStart=3 relay=0x9c priority=64)
```

You see: **Ch=0x8**

That means your T-Decks' behavior is same as mine and its configuration is correct. The default LongFast channel hash is **0x08**. Now the question is why your other nodes are sending with a different channel hash **0x0a** ??

mverch67, 2025-07-11:
This **0x0a** could be the your second encrypted channel on your other devices. But if they have another <empty name> LongFast channel with PSK AQ== then they would be able to decode the messages from your T-Deck. It seems they have not.

mverch67, 2025-07-11:
> -The T114 did not see the T Deck. The T Deck did not see the T114.

It takes a while to get other nodes' packets (especially in 2.7.x). Can take 15mins or longer. To speed up you can use MUI's Mesh Detektor. Then it takes only minutes.

MikeMesh, 2025-07-11:
> > -The T114 did not see the T Deck. The T Deck did not see the T114.
>
> It takes a while to get other nodes' packets (especially in 2.7.x). Can take 15mins or longer. To speed up you can use MUI's Mesh Detector. Then it takes only minutes.

Its been hours now. The T Deck is not being received.

Manuel, Thank you for your help. I officially give up on this one. Geez, it just crashed again. Wont respond until you turn it off then back on again.

Cheers

MikeMesh, 2025-07-12:
> I have already talked to the dealer and asked if we can send your device back to us for analysis. We have arranged for a new device to be sent to you. You should have received a reply from the dealer.

I have not heard from the dealer nor have I received a tracking number. I sure hope we make this in less than 2 weeks. Has it shipped?

lewisxhe, 2025-07-13:
Yes. I have already asked about it and they have sent it to the warehouse for shipping.

MikeMesh, 2025-07-20:
@lewisxhe The new unit arrived today and is working well. no issues at this point. I thank you very kindly. I appreciate your help very much.

While I was waiting for this replacement, I ordered another thru your web store just to be safe. It arrived a few days ago. It works fine on the network, but the battery is hard pressed to last 4 to 6 hours.

I dont care about warranty at this point as my presentation grows close.

Can you tell me-

1) Where can I buy a few spare batteries for these units?
2) Is there a larger capacity battery that I can buy, say 2500 or 3000 mah?

Thank you.

mverch67, 2025-07-20:
> Is there a larger capacity battery that I can buy, say 2500 or 3000 mah?

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

MikeMesh, 2025-07-20:
@mverch67

Got it. Thanks so 505070 is max size correct?

lewisxhe, 2025-07-22:
Yes.support

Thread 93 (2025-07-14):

T-Deck Plus caught in a reboot loop after setting RX/TX

tcanthony, 2025-07-14:
Just recieved my T-Deck Plus. Worked great after upgrading to 2.6.1 firmware. I did have a terrible time getting it to connect to client.meshtastic.com in Windows but was able to in Mac. Then I tried to set the RX and TX settings (RX44, TX43) and turn on GPS. Now it is caught in a reboot loop that I can't get it out of.
I have tried to "catch" it while rebooting so I can reflash it but it is booting too fast.
Any thoughts to get it out of the reboot loop?

lewisxhe, 2025-07-15:
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
Put it into download mode.

tcanthony, 2025-07-15:
This didn't change anything. I don't know what the resistor in issue62 is. Should I open the case?

tcanthony, 2025-07-15:
When I try to attach to the client.meshtastic.org via serial it just spins and doesn't connect.

tcanthony, 2025-07-15:
OK. I was able to catch it at just the right time to reflash it. Reboot loop is done.
Thank you.

Closed 2025-07-15.

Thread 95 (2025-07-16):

T-Deck Plus - LORA Radio not working (TX and RX not working)

ne0phaze, 2025-07-16:
I recently purchased a T-Deck Plus directly from Lilygo, and it worked for a while, but now when I try to send messages on Meshtastic I get error "no interface."

Troubleshooting
1. re-flashed latest 2.6.11 firmware from Meshtastic, with full erase
2. put T-Deck in Bluetooth programming mode
3. Verified radio configured for correct frequency and channel
4. Send test messages to Long Fast channel, receive message "no interface"
5. Flash Lilygo Function test firmware, (T-Deck_UnitTest_250620.bin),
 a. after flash, reboot
 b. under Radio menu, show message "Radio is offline"
4. check solder joints on Lora radio, did not see any broken joints
5. checked antenna cable and antenna, look fine

lewisxhe, 2025-07-17:
OK. Please take a video of burning the Lilygo functional test firmware, and then take a video of the Radio offline page, and send it to the dealer, and they will provide you with after-sales service.

Closed 2025-08-31.

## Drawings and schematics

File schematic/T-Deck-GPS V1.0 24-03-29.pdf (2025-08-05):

# GPS

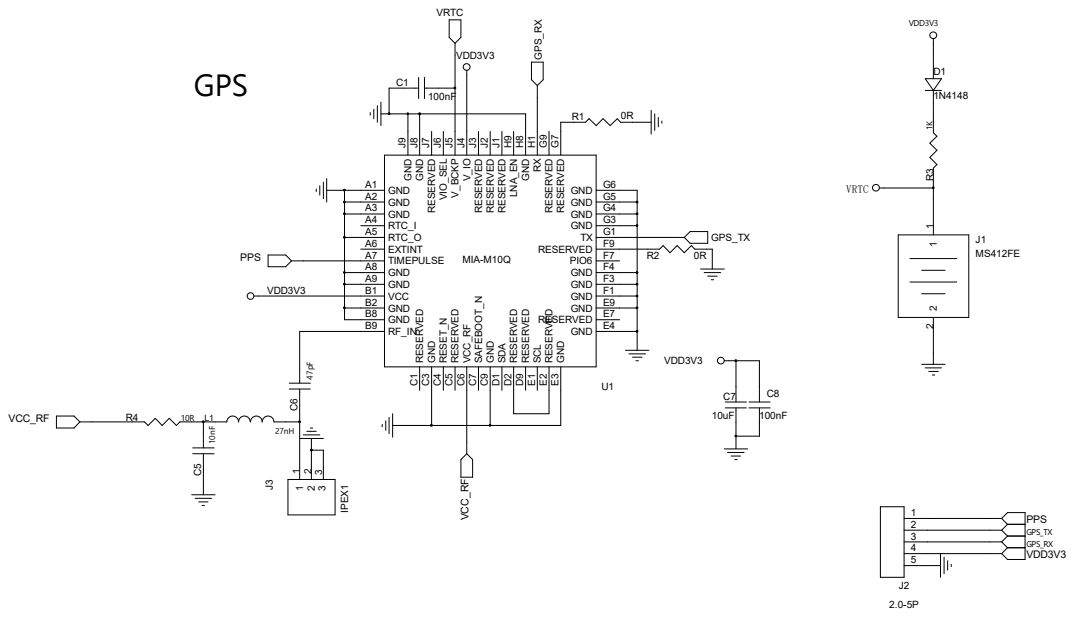
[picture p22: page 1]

G6 GND G⁷ RESERVED G⁹ RESERVED H¹ RX H⁸ GND H⁹ LNA_EN J1 RESERVED J2 RESERVED J3 RESERVED J4 V_IO J5 V_BCKP J6 VIO_SEL J7 RESERVED J8 GND J9 GND

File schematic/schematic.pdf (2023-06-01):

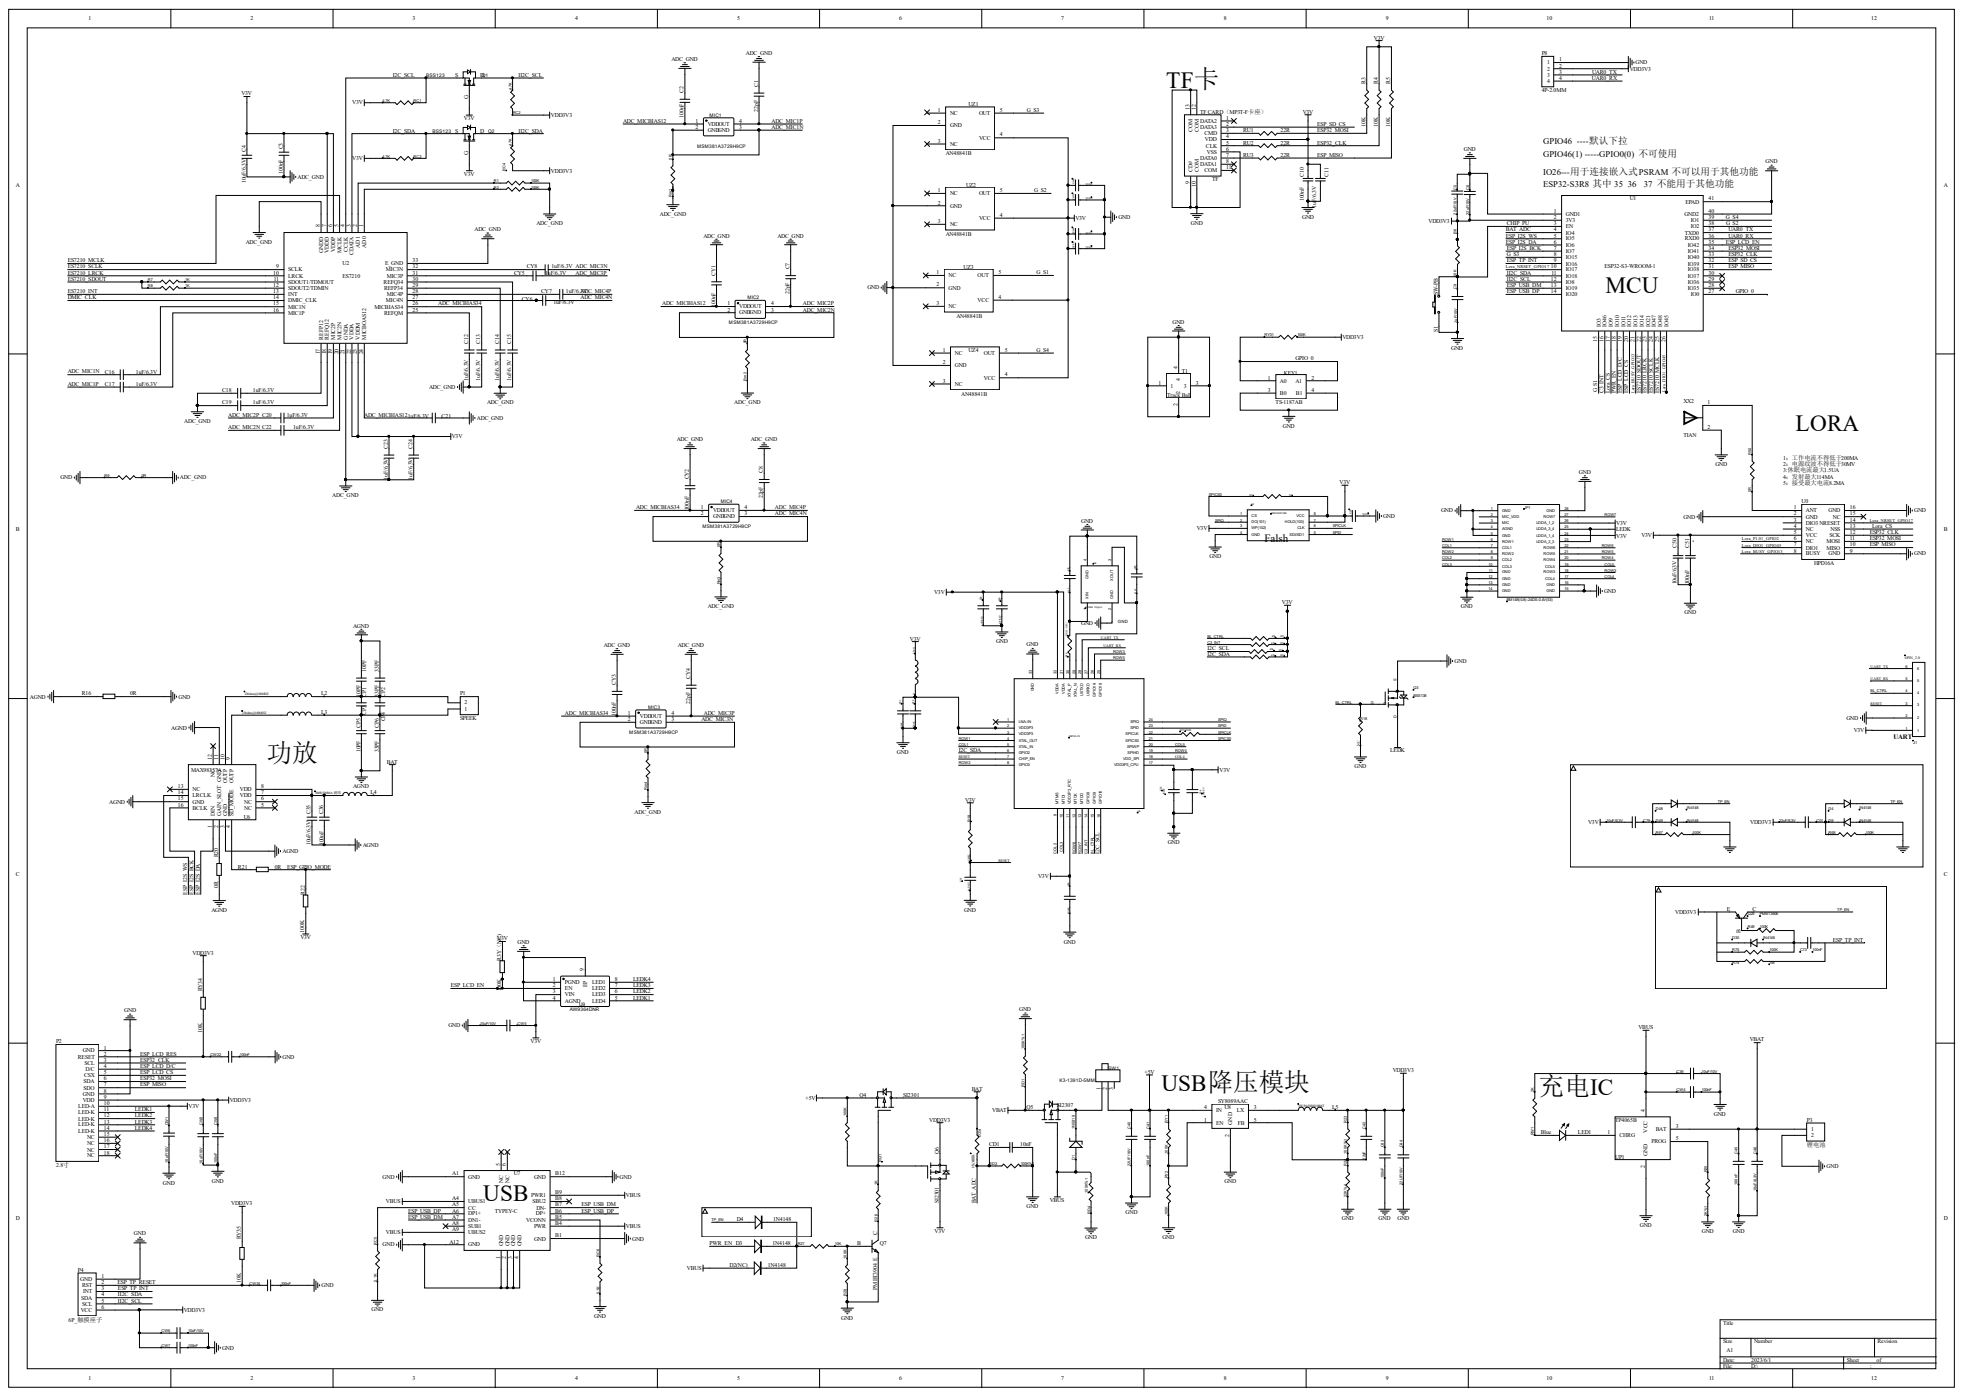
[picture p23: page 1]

AD0 1 AD1 2 CDATA 3 CCLK 4 MCLK 5 VDDP 6 VDDD 7 GNDD 8

MIC1P 16 | ADC_MIC2N | AN48841B

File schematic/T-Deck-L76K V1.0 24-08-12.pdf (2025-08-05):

# GPS

# 1N4148 R³ ¹K

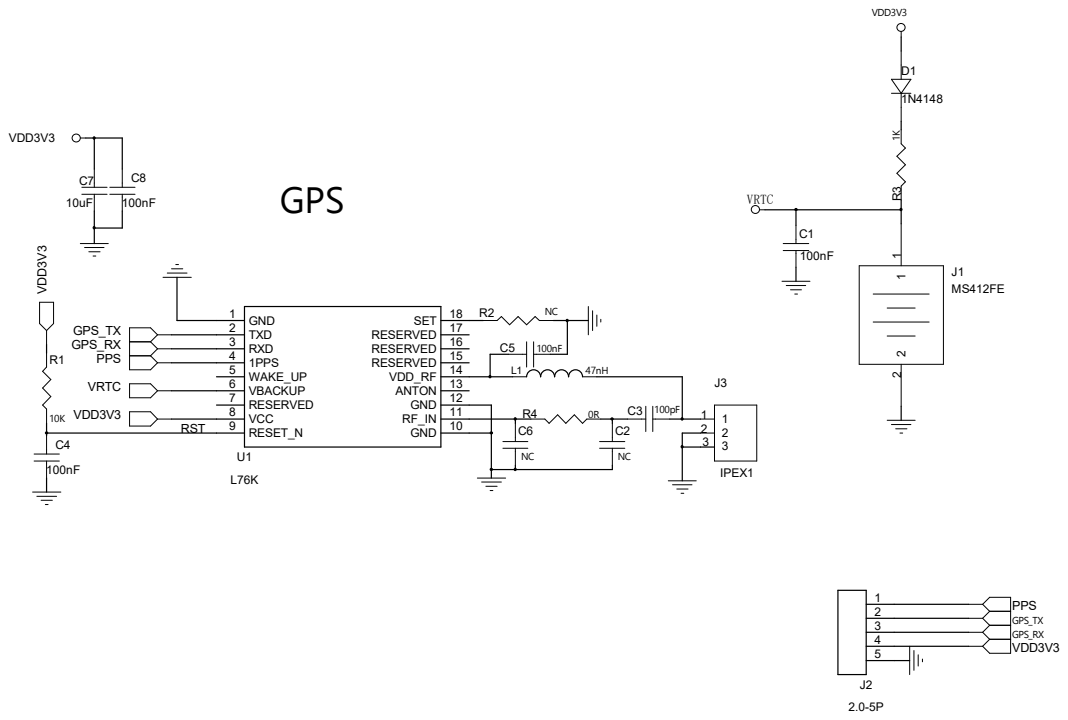
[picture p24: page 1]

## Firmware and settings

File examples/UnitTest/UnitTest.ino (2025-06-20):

/**
 * @file      UnitTest.ino
 * @author    Lewis He (lewishe@outlook.com)
 * @license   MIT
 * @copyright Copyright (c) 2023  Shenzhen Xin Yuan Electronic Technology Co., Ltd
 * @date      2023-04-11
 * @note      Arduino Setting
 *            Tools ->
 *                  Board:"ESP32S3 Dev Module"
 *                  USB CDC On Boot:"Enable"
 *                  USB DFU On Boot:"Disable"
 *                  Flash Size : "16MB(128Mb)"
 *                  Flash Mode"QIO 80MHz
 *                  Partition Scheme:"16M Flash(3M APP/9.9MB FATFS)"
 *                  PSRAM:"OPI PSRAM"
 *                  Upload Mode:"UART0/Hardware CDC"
 *                  USB Mode:"Hardware CDC and JTAG"
 */
#include <Arduino.h>
#include <SPI.h>
#include <RadioLib.h>
#include <TFT_eSPI.h>
#include <lvgl.h>
#include <SD.h>
#include "es7210.h"
#include <Audio.h>
#include <driver/i2s.h>
#include <WiFi.h>
#include "TouchDrvGT911.hpp"
#include <esp_sntp.h>

// By default, the audio pass-through speaker is used for testing, and esp_sr can also be used for noise detection.
#define USE_ESP_VAD

#include "utilities.h"
#include "config.h"

#ifndef BOARD_HAS_PSRAM
#error "Detected that PSRAM is not turned on. Please set PSRAM to OPI PSRAM in ArduinoIDE"
#endif

#ifndef SerialGPS
#define SerialGPS Serial1
#endif

#include <TinyGPS++.h>
TinyGPSPlus gps;
String gps_model = "None";

#define MIC_I2S_SAMPLE_RATE         16000
#define MIC_I2S_PORT                I2S_NUM_1
#define SPK_I2S_PORT                I2S_NUM_0
#define VAD_SAMPLE_RATE_HZ          16000
#define VAD_FRAME_LENGTH_MS         30
#define VAD_BUFFER_LENGTH           (VAD_FRAME_LENGTH_MS * VAD_SAMPLE_RATE_HZ / 1000)

#if TFT_DC !=  BOARD_TFT_DC || TFT_CS !=  BOARD_TFT_CS || TFT_MOSI !=  BOARD_SPI_MOSI || TFT_SCLK !=  BOARD_SPI_SCK
#error "Not using the already configured T-Deck file, please remove <Arduino/libraries/TFT_eSPI> and replace with <lib/TFT_eSPI>, please do not click the upgrade library button when opening sketches in ArduinoIDE versions 2.0 and above, otherwise the original configuration file will be replaced !!!"
#error "Not using the already configured T-Deck file, please remove <Arduino/libraries/TFT_eSPI> and replace with <lib/TFT_eSPI>, please do not click the upgrade library button when opening sketches in ArduinoIDE versions 2.0 and above, otherwise the original configuration file will be replaced !!!"
#error "Not using the already configured T-Deck file, please remove <Arduino/libraries/TFT_eSPI> and replace with <lib/TFT_eSPI>, please do not click the upgrade library button when opening sketches in ArduinoIDE versions 2.0 and above, otherwise the original configuration file will be replaced !!!"
#endif

#define LVGL_BUFFER_SIZE            (TFT_WIDTH * TFT_HEIGHT * sizeof(lv_color_t))


typedef struct {
    uint8_t cmd;
    uint8_t data[14];
    uint8_t len;
} lcd_cmd_t;

lcd_cmd_t lcd_st7789v[] = {
    {0x01, {0}, 0 | 0x80},
    {0x11, {0}, 0 | 0x80},
    {0x3A, {0X05}, 1},
    {0x36, {0x55}, 1},
    {0xB2, {0x0C, 0x0C, 0X00, 0X33, 0X33}, 5},
    {0xB7, {0X75}, 1},
    {0xBB, {0X1A}, 1},
    {0xC0, {0X2C}, 1},
    {0xC2, {0X01}, 1},
    {0xC3, {0X13}, 1},
    {0xC4, {0X20}, 1},
    {0xC6, {0X0F}, 1},
    {0xD0, {0XA4, 0XA1}, 2},
    {0xD6, {0XA1}, 1},
    {0xE0, {0XD0, 0X0D, 0X14, 0X0D, 0X0D, 0X09, 0X38, 0X44, 0X4E, 0X3A, 0X17, 0X18, 0X2F, 0X30}, 14},
    {0xE1, {0XD0, 0X09, 0X0F, 0X08, 0X07, 0X14, 0X37, 0X44, 0X4D, 0X38, 0X15, 0X16, 0X2C, 0X3E}, 14},
    {0x21, {0}, 0}, //invertDisplay
    {0x29, {0}, 0},
    {0x2C, {0}, 0},
};

TFT_eSPI        tft;
SemaphoreHandle_t xSemaphore = NULL;
TouchDrvGT911 touch;

lv_indev_t  *kb_indev = NULL;
lv_indev_t  *mouse_indev = NULL;
lv_indev_t  *touch_indev = NULL;
uint32_t    gps_start_ms = 0;

LV_IMG_DECLARE(image_emoji);



#ifdef USE_ESP_VAD
#include <esp_vad.h>
int16_t         *vad_buff;
vad_handle_t    vad_inst;
const size_t    vad_buffer_size = VAD_BUFFER_LENGTH * sizeof(short);
#else
uint16_t loopbackBuffer[3200] = {0};
#endif

SX1262 radio = new Module(RADIO_CS_PIN, RADIO_DIO1_PIN, RADIO_RST_PIN, RADIO_BUSY_PIN);
Audio           audio;
size_t          bytes_read;
uint8_t         status;
TaskHandle_t    playHandle = NULL;
TaskHandle_t    radioHandle = NULL;

static lv_obj_t *vad_btn_label;
static uint32_t vad_detected_counter = 0;
static TaskHandle_t vadTaskHandler;
bool        kbDetected = false;
bool        touchDetected = false;
bool        transmissionFlag = true;
bool        enableInterrupt = true;
int         transmissionState ;
bool        hasRadio = false;
bool        sender = true;
bool        enterSleep = false;
uint32_t    sendCount = 0;
uint32_t    configTxInterval = 1000;
uint32_t    last_update_millis = 0;


lv_obj_t    *main_count;





static void setupLvgl();
static void keypad_read(lv_indev_drv_t *indev_drv, lv_indev_data_t *data);
static uint32_t keypad_get_key(void);
static void touchpad_read( lv_indev_drv_t *indev_driver, lv_indev_data_t *data );
static void mouse_read(lv_indev_drv_t *indev, lv_indev_data_t *data);
static void disp_flush( lv_disp_drv_t *disp, const lv_area_t *area, lv_color_t *color_p );
static bool GPS_Recovery();



extern void updateGPS(double lat, double lng,
                      uint16_t year, uint8_t month, uint8_t day,
                      uint8_t hour, uint8_t minute, uint8_t second,
                      double speed, uint32_t rx_char, uint32_t use_sec);
extern void updateNoiseLabel(uint32_t cnt);
extern void setLoRaMessage(const char *text);
extern void setupUI(void);


bool setupGPS()
{
    SerialGPS.begin(9600, SERIAL_8N1, BOARD_GPS_RX_PIN, BOARD_GPS_TX_PIN);

    bool result = false;
    uint32_t startTimeout ;
    for (int i = 0; i < 3; ++i) {
        SerialGPS.write("$PCAS03,0,0,0,0,0,0,0,0,0,0,,,0,0*02\r\n");
        delay(5);
        // Get version information
        startTimeout = millis() + 3000;
        Serial.print("Try to init L76K . Wait stop .");
        while (SerialGPS.available()) {
            Serial.print(".");
            SerialGPS.readString();
            if (millis() > startTimeout) {
                Serial.println("Wait L76K stop NMEA timeout!");
                return false;
            }
        };
        Serial.println();
        SerialGPS.flush();
        delay(200);

        SerialGPS.write("$PCAS06,0*1B\r\n");
        startTimeout = millis() + 500;
        String ver = "";
        while (!SerialGPS.available()) {
            if (millis() > startTimeout) {
                Serial.println("Get L76K timeout!");
                return false;
            }
        }
        SerialGPS.setTimeout(10);
        ver = SerialGPS.readStringUntil('\n');
        if (ver.startsWith("$GPTXT,01,01,02")) {
            Serial.println("L76K GNSS init succeeded, using L76K GNSS Module\n");
            gps_model = "L76K";
            result = true;
            break;
        }
        delay(500);
    }
    // Initialize the L76K Chip, use GPS + GLONASS
    SerialGPS.write("$PCAS04,5*1C\r\n");
    delay(250);
    // only ask for RMC and GGA
    SerialGPS.write("$PCAS03,1,0,0,0,1,0,0,0,0,0,,,0,0*02\r\n");
    delay(250);
    // Switch to Vehicle Mode, since SoftRF enables Aviation < 2g
    SerialGPS.write("$PCAS11,3*1E\r\n");
    return result;
}

static void time_available_cb(struct timeval *t)
{
    Serial.println("Got time adjustment from NTP!");
}

static void wifi_event_cb(WiFiEvent_t event)
{
    Serial.printf("[WiFi-event] event: %d\n", event);

    switch (event) {
    case ARDUINO_EVENT_WIFI_READY:
        Serial.println("WiFi interface ready");
        break;
    case ARDUINO_EVENT_WIFI_SCAN_DONE:
        Serial.println("Completed scan for access points");
        break;
    case ARDUINO_EVENT_WIFI_STA_START:
        Serial.println("WiFi client started");
        break;
    case ARDUINO_EVENT_WIFI_STA_STOP:
        Serial.println("WiFi clients stopped");
        break;
    case ARDUINO_EVENT_WIFI_STA_CONNECTED:
        Serial.println("Connected to access point");
        break;
    case ARDUINO_EVENT_WIFI_STA_DISCONNECTED:
        Serial.println("Disconnected from WiFi access point");
        lv_msg_send(_BV(1), NULL);
        break;
    case ARDUINO_EVENT_WIFI_STA_AUTHMODE_CHANGE:
        Serial.println("Authentication mode of access point has changed");
        break;
    case ARDUINO_EVENT_WIFI_STA_GOT_IP:
        Serial.print("Obtained IP address: ");
        Serial.println(WiFi.localIP());
        lv_msg_send(_BV(1), NULL);
        break;
    case ARDUINO_EVENT_WIFI_STA_LOST_IP:
        Serial.println("Lost IP address and IP address is reset to 0");
        lv_msg_send(_BV(1), NULL);
        break;
    default: break;
    }
}


void setupWiFi()
{
    WiFi.onEvent(wifi_event_cb);
    WiFi.begin(WIFI_SSID, WIFI_PASSWORD);

    configTzTime(DEFAULT_TIMEZONE, NTP_SERVER1, NTP_SERVER2);
    // set notification call-back function
    sntp_set_time_sync_notification_cb(time_available_cb);

}

// LilyGo  T-Deck  control backlight chip has 16 levels of adjustment range
// The adjustable range is 0~16, 0 is the minimum brightness, 16 is the maximum brightness
void setBrightness(uint8_t value)
{
    static uint8_t level = 0;
    static uint8_t steps = 16;
    if (value == 0) {
        digitalWrite(BOARD_BL_PIN, 0);
        delay(3);
        level = 0;
        return;
    }
    if (level == 0) {
        digitalWrite(BOARD_BL_PIN, 1);
        level = steps;
        delayMicroseconds(30);
    }
    int from = steps - level;
    int to = steps - value;
    int num = (steps + to - from) % steps;
    for (int i = 0; i < num; i++) {
        digitalWrite(BOARD_BL_PIN, 0);
        digitalWrite(BOARD_BL_PIN, 1);
    }
    level = value;
}

void setFlag(void)
{
    // check if the interrupt is enabled
    if (!enableInterrupt) {
        return;
    }
    // we got a packet, set the flag
    transmissionFlag = true;
}

bool setupRadio()
{
    digitalWrite(BOARD_SDCARD_CS, HIGH);
    digitalWrite(RADIO_CS_PIN, HIGH);
    digitalWrite(BOARD_TFT_CS, HIGH);
    SPI.end();
    SPI.begin(BOARD_SPI_SCK, BOARD_SPI_MISO, BOARD_SPI_MOSI); //SD

    int state = radio.begin();
    if (state == RADIOLIB_ERR_NONE) {
        Serial.println("Start Radio success!");
    } else {
        Serial.print("Start Radio failed,code:");
        Serial.println(state);
        // T-Deck without LoRa, reinitialize SPI
        SPI.begin(BOARD_SPI_SCK, BOARD_SPI_MISO, BOARD_SPI_MOSI);
        return false;
    }

    Serial.printf("Freq:%.2f TxPower:%d Bandwidth:%.2f\n", RADIO_FREQ, RADIO_TX_POWER, RADIO_BANDWIDTH);

    hasRadio = true;

    // set carrier frequency to 868.0 MHz
    if (radio.setFrequency(RADIO_FREQ) == RADIOLIB_ERR_INVALID_FREQUENCY) {
        Serial.println(F("Selected frequency is invalid for this module!"));
        return false;
    }

    // set bandwidth to 125 kHz
    if (radio.setBandwidth(RADIO_BANDWIDTH) == RADIOLIB_ERR_INVALID_BANDWIDTH) {
        Serial.println(F("Selected bandwidth is invalid for this module!"));
        return false;
    }

    // set spreading factor to 10
    if (radio.setSpreadingFactor(RADIO_SF) == RADIOLIB_ERR_INVALID_SPREADING_FACTOR) {
        Serial.println(F("Selected spreading factor is invalid for this module!"));
        return false;
    }

    // set coding rate to 6
    if (radio.setCodingRate(RADIO_CR) == RADIOLIB_ERR_INVALID_CODING_RATE) {
        Serial.println(F("Selected coding rate is invalid for this module!"));
        return false;
    }

    // set LoRa sync word to 0xAB
    if (radio.setSyncWord(0xAB) != RADIOLIB_ERR_NONE) {
        Serial.println(F("Unable to set sync word!"));
        return false;
    }

    // set output power to 22 dBm (accepted range is -17 - 22 dBm)
    if (radio.setOutputPower(RADIO_TX_POWER) == RADIOLIB_ERR_INVALID_OUTPUT_POWER) {
        Serial.println(F("Selected output power is invalid for this module!"));
        return false;
    }

    // set over current protection limit to 140 mA (accepted range is 45 - 140 mA)
    // NOTE: set value to 0 to disable overcurrent protection
    if (radio.setCurrentLimit(140) == RADIOLIB_ERR_INVALID_CURRENT_LIMIT) {
        Serial.println(F("Selected current limit is invalid for this module!"));
        return false;
    }

    // set LoRa preamble length to 15 symbols (accepted range is 0 - 65535)
    if (radio.setPreambleLength(15) == RADIOLIB_ERR_INVALID_PREAMBLE_LENGTH) {
        Serial.println(F("Selected preamble length is invalid for this module!"));
        return false;
    }

    // disable CRC
    if (radio.setCRC(false) == RADIOLIB_ERR_INVALID_CRC_CONFIGURATION) {
        Serial.println(F("Selected CRC is invalid for this module!"));
        return false;
    }

    // set the function that will be called
    // when new packet is received
    radio.setDio1Action(setFlag);
    return true;

}

bool setupSD()
{
    digitalWrite(BOARD_SDCARD_CS, HIGH);
    digitalWrite(RADIO_CS_PIN, HIGH);
    digitalWrite(BOARD_TFT_CS, HIGH);

    if (SD.begin(BOARD_SDCARD_CS, SPI, 800000U)) {
        uint8_t cardType = SD.cardType();
        if (cardType == CARD_NONE) {
            Serial.println("No SD_MMC card attached");
            return false;
        } else {
            Serial.print("SD_MMC Card Type: ");
            if (cardType == CARD_MMC) {
                Serial.println("MMC");
            } else if (cardType == CARD_SD) {
                Serial.println("SDSC");
            } else if (cardType == CARD_SDHC) {
                Serial.println("SDHC");
            } else {
                Serial.println("UNKNOWN");
            }
            uint32_t cardSize = SD.cardSize() / (1024 * 1024);
            uint32_t cardTotal = SD.totalBytes() / (1024 * 1024);
            uint32_t cardUsed = SD.usedBytes() / (1024 * 1024);
            Serial.printf("SD Card Size: %lu MB\n", cardSize);
            Serial.printf("Total space: %lu MB\n",  cardTotal);
            Serial.printf("Used space: %lu MB\n",   cardUsed);
            return true;
        }
    }
    return false;
}
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
void loop()
{
    if (enterSleep) {

        vTaskDelete(playHandle);
        playHandle = NULL;

#ifdef USE_ESP_VAD
        vTaskDelete(vadTaskHandler);
        vadTaskHandler = NULL;
#endif

        //LilyGo T-Deck control backlight chip has 16 levels of adjustment range
        for (int i = 16; i > 0; --i) {
            setBrightness(i);
            delay(30);
        }

        delay(1000);

        //If you need other peripherals to maintain power, please set the IO port to hold
        // gpio_hold_en((gpio_num_t)BOARD_POWERON);
        // gpio_deep_sleep_hold_en();

        touch.sleep();        //set touchpad enter sleep mode
        tft.writecommand(0x10);      //set display enter sleep mode
        SPI.end();
        Wire.end();
        esp_sleep_enable_ext1_wakeup(1ull << BOARD_BOOT_PIN, ESP_EXT1_WAKEUP_ALL_LOW);
        esp_deep_sleep_start();
        //Deep sleep consumes approximately 240uA of current
    }

    loopRadio();
    loopGPS();
    lv_task_handler();
}



// !!! LVGL !!!
// !!! LVGL !!!
// !!! LVGL !!!
static void disp_flush( lv_disp_drv_t *disp, const lv_area_t *area, lv_color_t *color_p )
{
    uint32_t w = ( area->x2 - area->x1 + 1 );
    uint32_t h = ( area->y2 - area->y1 + 1 );
    if ( xSemaphoreTake( xSemaphore, portMAX_DELAY ) == pdTRUE ) {
        tft.startWrite();
        tft.setAddrWindow( area->x1, area->y1, w, h );
        tft.pushColors( ( uint16_t * )&color_p->full, w * h, false );
        tft.endWrite();
        lv_disp_flush_ready( disp );
        xSemaphoreGive( xSemaphore );
    }
}

static void mouse_read(lv_indev_drv_t *indev, lv_indev_data_t *data)
{
    static  int16_t last_x;
    static int16_t last_y;
    bool left_button_down = false;
    const uint8_t dir_pins[5] = {BOARD_TBOX_G02,
                                 BOARD_TBOX_G01,
                                 BOARD_TBOX_G04,
                                 BOARD_TBOX_G03,
                                 BOARD_BOOT_PIN
                                };
    static bool last_dir[5];
    uint8_t pos = 10;
    for (int i = 0; i < 5; i++) {
        bool dir = digitalRead(dir_pins[i]);
        if (dir != last_dir[i]) {
            last_dir[i] = dir;
            switch (i) {
            case 0:
                if (last_x < (lv_disp_get_hor_res(NULL) - image_emoji.header.w)) {
                    last_x += pos;
                }
                break;
            case 1:
                if (last_y > image_emoji.header.h) {
                    last_y -= pos;
                }
                break;
            case 2:
                if (last_x > image_emoji.header.w) {
                    last_x -= pos;
                }
                break;
            case 3:
                if (last_y < (lv_disp_get_ver_res(NULL) - image_emoji.header.h)) {
                    last_y += pos;
                }
                break;
            case 4:
                left_button_down = true;
                break;
            default:
                break;
            }
        }
    }
    // Serial.printf("indev:X:%04d  Y:%04d \n", last_x, last_y);
    /*Store the collected data*/
    data->point.x = last_x;
    data->point.y = last_y;
    data->state = left_button_down ? LV_INDEV_STATE_PRESSED : LV_INDEV_STATE_RELEASED;
}

/*Read the touchpad*/
static void touchpad_read( lv_indev_drv_t *indev_driver, lv_indev_data_t *data )
{
    static int16_t x[5], y[5];
    data->state =  LV_INDEV_STATE_REL;
    if (touch.isPressed()) {
        uint8_t touched = touch.getPoint(x, y, 1);
        if (touched > 0) {
            data->state = LV_INDEV_STATE_PR;
            data->point.x = x[0];
            data->point.y = y[0];
        }
    }
}

// Read key value from esp32c3
static uint32_t keypad_get_key(void)
{
    static uint32_t retry = 0;
    char key_ch = 0;
    if (retry > 10) {
        lv_indev_delete(kb_indev);
        kb_indev = NULL;
        return 0;
    }
    Wire.beginTransmission(0x55);
    if (Wire.endTransmission() != 0) {
        Serial.println("Keyboard Failed!");
        retry++;
        return 0;
    }
    Wire.requestFrom(0x55, 1);
    while (Wire.available() > 0) {
        key_ch = Wire.read();
        retry = 0;
    }
    return key_ch;
}

/*Will be called by the library to read the mouse*/
static void keypad_read(lv_indev_drv_t *indev_drv, lv_indev_data_t *data)
{
    static uint32_t last_key = 0;
    uint32_t act_key ;
    act_key = keypad_get_key();
    if (act_key != 0) {
        data->state = LV_INDEV_STATE_PR;
        Serial.printf("Key pressed : 0x%x\n", act_key);
        last_key = act_key;
    } else {
        data->state = LV_INDEV_STATE_REL;
    }
    data->key = last_key;
}

static void setupLvgl()
{
    static lv_disp_draw_buf_t draw_buf;
    static lv_color_t *buf = (lv_color_t *)ps_malloc(LVGL_BUFFER_SIZE);
    if (!buf) {
        Serial.println("memory alloc failed!");
        delay(5000);
        assert(buf);
    }
    String LVGL_Arduino = "Hello Arduino! ";
    LVGL_Arduino += String('V') + lv_version_major() + "." + lv_version_minor() + "." + lv_version_patch();
    Serial.println( LVGL_Arduino );
    Serial.println( "I am LVGL_Arduino" );

    lv_init();

    lv_group_set_default(lv_group_create());

    lv_disp_draw_buf_init( &draw_buf, buf, NULL, LVGL_BUFFER_SIZE );

    /*Initialize the display*/
    static lv_disp_drv_t disp_drv;
    lv_disp_drv_init( &disp_drv );

    /*Change the following line to your display resolution*/
    disp_drv.hor_res = TFT_HEIGHT;
    disp_drv.ver_res = TFT_WIDTH;
    disp_drv.flush_cb = disp_flush;
    disp_drv.draw_buf = &draw_buf;
    disp_drv.full_refresh = 1;
    lv_disp_drv_register( &disp_drv );

    /*Initialize the  input device driver*/

    /*Register a touchscreen input device*/
    if (touchDetected) {
        static lv_indev_drv_t indev_touchpad;
        lv_indev_drv_init( &indev_touchpad );
        indev_touchpad.type = LV_INDEV_TYPE_POINTER;
        indev_touchpad.read_cb = touchpad_read;
        touch_indev = lv_indev_drv_register( &indev_touchpad );
    }

    /*Register a mouse input device*/
    static lv_indev_drv_t indev_mouse;
    lv_indev_drv_init( &indev_mouse );
    indev_mouse.type = LV_INDEV_TYPE_POINTER;
    indev_mouse.read_cb = mouse_read;
    mouse_indev = lv_indev_drv_register( &indev_mouse );
    lv_indev_set_group(mouse_indev, lv_group_get_default());

    lv_obj_t *cursor_obj;
    cursor_obj = lv_img_create(lv_scr_act());         /*Create an image object for the cursor */
    lv_img_set_src(cursor_obj, &image_emoji);   /*Set the image source*/
    lv_indev_set_cursor(mouse_indev, cursor_obj);           /*Connect the image  object to the driver*/

    if (kbDetected) {
        Serial.println("Keyboard registered!!");
        /*Register a keypad input device*/
        static lv_indev_drv_t indev_keypad;
        lv_indev_drv_init(&indev_keypad);
        indev_keypad.type = LV_INDEV_TYPE_KEYPAD;
        indev_keypad.read_cb = keypad_read;
        kb_indev = lv_indev_drv_register(&indev_keypad);
        lv_indev_set_group(kb_indev, lv_group_get_default());
    }
}







uint8_t buffer[256];
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

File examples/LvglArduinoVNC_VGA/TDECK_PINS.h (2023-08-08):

#pragma once

//! The board peripheral power control pin needs to be set to HIGH when using the peripheral
#define TDECK_PERI_POWERON 10

#define TDECK_SPI_MOSI 41
#define TDECK_SPI_MISO 38
#define TDECK_SPI_SCK 40

#define TDECK_SDCARD_CS 39

#define TDECK_TFT_CS 12
#define TDECK_TFT_DC 11
#define TDECK_TFT_BACKLIGHT 42

#define TDECK_RADIO_CS 9
#define TDECK_RADIO_BUSY 13
#define TDECK_RADIO_RST 17
#define TDECK_RADIO_DIO1 45

#define TDECK_I2C_SDA 18
#define TDECK_I2C_SCL 8

#define TDECK_TOUCH_INT 16
#define TDECK_KEYBOARD_INT 46

#define TDECK_KEYBOARD_ADDR 0x55

#define TDECK_TRACKBALL_UP 3
#define TDECK_TRACKBALL_DOWN 15
#define TDECK_TRACKBALL_LEFT 1
#define TDECK_TRACKBALL_RIGHT 2
#define TDECK_TRACKBALL_CLICK 0

#define TDECK_ES7210_MCLK 48
#define TDECK_ES7210_LRCK 21
#define TDECK_ES7210_SCK 47
#define TDECK_ES7210_DIN 14

#define TDECK_I2S_WS 5
#define TDECK_I2S_BCK 7
#define TDECK_I2S_DOUT 6

#define TDECK_BAT_ADC 4

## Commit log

2023-04-11 Added ESP32C3 Keyboard example
2023-04-14 Fix I2C Scan
2023-05-30 Rename track pin
2023-06-01 Added schematic
2023-06-01 Added dxf ,raname dir
    [T-Deck 3D.stp, T-Deck.dxf, T-Deck.stp]
2023-06-07 Fix ArduinoIDE compilation errors
    [UnitTest.ino]
2023-07-24 Use I2CProbe to get address of different brand touches
2023-08-28 Keyboard_ESP32C3: fix i2c setup as peripheral
    for some reason with my version of platformio, the call to
    Wire.begin((uint8_t)I2C_DEV_ADDR, SDA, SCL);
    will resolve to controller setup instead of peripheral setup, and wrong
    parameters for it:
    entry 0x403cc710
    [ 44][I][esp32-hal-i2c.c:75] i2cInit(): Initialising I2C Master: sda=85 scl=2 freq=10
    [ 44][E][esp32-hal-i2c.c:88] i2cInit(): i2c_param_config failed
    Starting keyboard work!
    to call the correct overloaded function for peripheral setup, add 0 to
    the call for the default frequency. with this, peripheral setup works
    and the keyboard can communicate with the t-deck esp32s3 successfully:
    entry 0x403cc710
    [ 44][I][esp32-hal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
    [Keyboard_ESP32C3.ino]
2024-03-26 Added PCB 3C https://github.com/Xinyuan-LilyGO/T-Deck/issues/22
    [T-Deck-PCB-3D.stp]
2024-07-26 Added custom board
2024-08-10 Added Shell
    [T-Deck-Shell.stp]
2024-09-04 lvgl_example Touch interrupt method https://github.com/Xinyuan-LilyGO/T-Deck/issues/42
    [lvgl_example.ino]
2024-09-18 Fix Arduino IDE compilation
    [UnitTest.ino]
2024-09-19 Add Arduino_GFX lib
2024-10-21 Remove touch interrupt control.
2024-10-24 Add a simple example https://github.com/Xinyuan-LilyGO/T-Deck/issues/59
    [HelloWorld.ino, utilities.h]
2024-10-28 Added plus shell https://github.com/Xinyuan-LilyGO/T-Deck/issues/60
    [T-Deck-Plus-Shell.stp]
2024-11-14 Added play mp3 examples https://github.com/Xinyuan-LilyGO/T-Deck/issues/63
    [I2SPlay.ino, utilities.h]
2024-12-18 Fix typos and the backlight function key sends the character 'b' https://github.com/Xinyuan-LilyGO/T-Deck/issues/69
    [Keyboard_ESP32C3.ino]
2024-12-20 Fixed the stuck boot screen caused by lack of LoRa
    [UnitTest.ino, ui.cpp]
2024-12-24 Fixed SYM function https://github.com/Xinyuan-LilyGO/T-Deck/issues/70
    [Keyboard_ESP32C3.ino]
2025-03-16 Fix ledc error reported over serial on boot.
    [Keyboard_ESP32C3.ino]
2025-03-31 Added T-Deck mesh device-ui fw
2025-06-20 ESP32C3 Keyboard firmware add revision notes
2025-09-25 Added i2s tone https://github.com/Xinyuan-LilyGO/T-Deck/issues/99#issuecomment-3329099006
    [SimpleTone.ino]
